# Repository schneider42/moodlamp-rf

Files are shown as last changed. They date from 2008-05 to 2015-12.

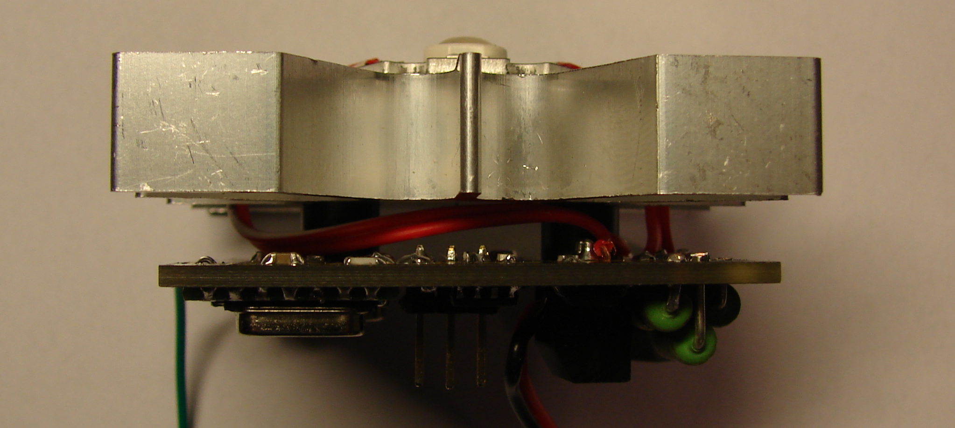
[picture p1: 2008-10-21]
media/side.jpeg

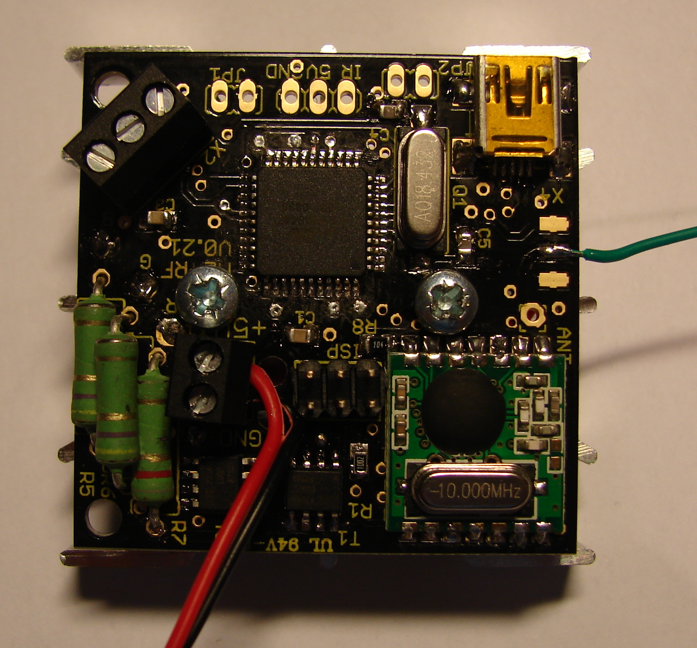
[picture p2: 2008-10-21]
media/bot.jpeg

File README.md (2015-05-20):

# moodlamp
The moodlamp allows to change color in RGB colorspace.

Some art has been done with the help of moodlamps:
- ACAB (AllColourAreBeautiful) https://wiki.muc.ccc.de/acab:start
- Die Drei C https://wiki.muc.ccc.de/diedreic

# r3 version and earlier versions
Earlier versions are developed with ATmega324P, ATmega644P, ... For RS485 usage, change the MCU section in the file ubloader/Makefile.

# r4 version (2th quarter 2015)
Latest r4 version is designed with ATmega324A. If you get a warning from avrdude "device signature [..] expected signature [..] or use -F to override this check", put the following lines in your avrdude.conf:
```diff
 #------------------------------------------------------------
+# ATmega324A
+#------------------------------------------------------------
+
+# similar to ATmega324P
+
+part parent "m324p"
+    id               = "m324a";
+    desc             = "ATmega324A";
+    signature        = 0x1e 0x95 0x15;
+
+    ocdrev           = 3;
+  ;
+
+#------------------------------------------------------------
 # ATmega324PA
 #------------------------------------------------------------
```
For RS485 usage, also double check the MCU part in the file ubloader/Makefile.

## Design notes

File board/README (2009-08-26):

                          Moodlamp-rf pcb readme

This directory contains all files needed to build a moodlamp-rf board. Please use eagle in version 5 to view ml-rf.sch and ml-rf.brd

If you don't have eagle installed you can view the board using ml-rf-{brd,sch}.{png,pdf}

Please view the schematic to see which parts you have to put on the board. Different options are grouped together.
The file bom-grouped contains the list of parts used to build your moodlamp.

Special Notes:
R23 changed it's name to L1.

Parts not populated or replaced:
Some parts are not populated and some have been replaced by solder bridges:

Parts not populated:                    R13, R14, R15
Parts replaced by a solder bridge:      L1, R10, R11, R12

The 3V regulater is usually not populated. These parts are probably not included in your kit.

Parts not populated: C6, C7, C8, C9, C10, IC3
Solderbridge to short out: SJ1

Please refer to https://wiki.muc.ccc.de/geekend08:moodlamp_howto for more information about building a moodlamp.

For an introduction to SMD soldering visit http://www.spida.net/projects/hardware/smd-soldering/

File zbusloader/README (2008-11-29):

zbusloader v0.01
-------------------

zbusloader is a bootloader application targetted at the Atmel AVR
ATmega8.  In theory it should work for other devices but since
it heavily relies on assembler code, especially regarding the
startup code, this probably requires quite some adjustments.

One of the main design goals is to keep the loader small in flash
memory footprint.  This is I shouldn't ever be more than 512 bytes long.

a) Using zbusloader

   * make sure you've got gcc-avr and avr-libc installed

   * edit pinconfig.h to fit your needs

   * Type `make' to compile the whole thing.

   * If everything goes well, type `make load' to flash the
     bootloader code to your device.  Maybe you need to modify the
     command, i.e. the Makefile.

   * In order to adjust the fuse bits of your microcontroller you
     might want to use `make fuse'.

   In order to flash data, use the zbusloader application from below
   contrib.  Use it something like 

   	     contrib/zbusloader -H 192.168.23.244 -f myfile.bin

   where -H specifies the IP address of your (bridging) ethersex.
   Don't forget to enable `zbus_raw' on it.

b) Hacking zbusloader (and what hacks I used already)

   Just a few notes to get you started in zbusloader hacking:

   * zbusloader does NOT rely on avr-libc's standard startup code,
     mainly for size reasons.  This is

      * you must NOT activate any other interrupts, since there is no
        intact interrupt vector table

      * don't just `sei' if you want to, this reenables the overflow
        interrupt of timer 1, see below.

      * my startup code does NOT initialize .bss and .data, this is
        your global variables will not have the values you expect.

   * TIMER 1 OVF interrupt abuse:
     The current bootloader timeout implementation works like this:

      * We initialize the 16-bit timer in such a way that it overflows
        after about 2 seconds.  From the interrupt vector we launch
        the application

      * If we receive a valid bootloading packet we simply disable all
        interrupts, therefore the automatic activation of the
        application.

If it doesn't work, you might want to write an e-mail to
<stesie@brokenpipe.de> or <stettberger@dokucode.de>

Have fun!
  stesie && stettberger

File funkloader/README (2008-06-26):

funkloader v0.01
-------------------

funkloader is a bootloader application targetted at the Atmel AVR
ATmega8.  In theory it should work for other devices but since
it heavily relies on assembler code, especially regarding the
startup code, this probably requires quite some adjustments.

One of the main design goals is to keep the loader small in flash
memory footprint.  This is I shouldn't ever be more than 512 bytes long.

a) Using funkloader

   * make sure you've got gcc-avr and avr-libc installed

   * edit pinconfig.h to fit your needs

   * Type `make' to compile the whole thing.

   * If everything goes well, type `make load' to flash the
     bootloader code to your device.  Maybe you need to modify the
     command, i.e. the Makefile.

   * In order to adjust the fuse bits of your microcontroller you
     might want to use `make fuse'.

   In order to flash data, use the funkloader application from below
   contrib.  Use it something like 

   	     contrib/funkloader -H 192.168.23.244 -f myfile.bin

   where -H specifies the IP address of your (bridging) ethersex.
   Don't forget to enable `rfm12_raw' on it.

b) Hacking funkloader (and what hacks I used already)

   Just a few notes to get you started in funkloader hacking:

   * funkloader does NOT rely on avr-libc's standard startup code,
     mainly for size reasons.  This is

      * you must NOT activate any other interrupts, since there is no
        intact interrupt vector table

      * don't just `sei' if you want to, this reenables the overflow
        interrupt of timer 1, see below.

      * my startup code does NOT initialize .bss and .data, this is
        your global variables will not have the values you expect.

   * TIMER 1 OVF interrupt abuse:
     The current bootloader timeout implementation works like this:

      * We initialize the 16-bit timer in such a way that it overflows
        after about 2 seconds.  From the interrupt vector we launch
        the application

      * If we receive a valid bootloading packet we simply disable all
        interrupts, therefore the automatic activation of the
        application.

If it doesn't work, you might want to write an e-mail to
<stesie@brokenpipe.de>

Have fun!
  stesie

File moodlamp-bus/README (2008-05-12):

----moodlamp-ng---

This is a modified fnordlicht firmware by Tobias Schneider
(schneider@blinkenlichts.net).

It adds a more useful RC5 interface to control the lamp via
an infrared remote control.

Most of the added code goes to the static scripts and the rc5 handler.
The main loop contains a new state machine which controls the global
behavior of the lamp.

A list of features:
    -Dimming the lamp.
    -Powering down the lamp and resuming at the same state.
    -Storing default values in the internal eeprom, which are used at start up.
    -Selection of the running script.
    -Pausing the running script.
    -Adjusting the speed of the script running.
    -A sleep timer which dims the lamp over a period of time to zero brightness.
    -The RGB value can be directly modified by the remote.
     If this is used while the lamp is paused, any color can be selected.

Changes in the source:
    -The original RC5 decoder is replaced by Peter Dannegers code.
    -The speed adjustment is more thoroughly implemented.
    -The PWM values are scaled by a dimming value.
    -The RC5 commands are handled in a new module(rc5_handler.c)
    -The standard avr-lib makefile is used.
    -The pin for the RC5 receiver changed. This is due to the chosen layout.
     With the new RC5 lib this can be changed to any pin.

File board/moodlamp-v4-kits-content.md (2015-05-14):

```
Part                                Type        Value           Marking
IC1                                 MCU         ATMEGA324A-20AU ATMEGA324A AU
IC2                                 RS485 TRX   MAX487          MAX487
IC4                                 Regulator   LM2596DSADJG    2596-ADJ
T1, T2                              Transistor  IRF7103         F7103

C1, C2, C3, C7, C11, C12, C13, C14  Capacitor   100 nF          neutral marking on tape, 10 devices
C4, C5                              Capacitor   22 pF           red marking on tape, 2 devices
C6                                  Capacitor   6.8 nF          neutral marking on tape, 1 device
C8                                  Capacitor   10 uF           "Big Capacitor"
C9                                  Capacitor   220 uF/50 V     220 HFK
C10                                 Capacitor   470 uF/25 V     470 EFK

R1,R3                               Resistor    10 KOhm         1002, black marking on tape
R2                                  Resistor    150 kOhm        1503, blue marking on tape, 1 device
R4                                  Resistor    1 kOhm          1001, yellow marking on tape, 1 device
R5, R6                              Resistor    4.7 Ohm         Yellow-Purple-Gold-Gold
R7                                  Resistor    8.2 Ohm         Purple-Red-Gold-Gold
R9                                  Resistor    3.09 kOhm       purple marking on tape, 1 device

L1                                  Inductor    68 uH           "Big Inductor"
L2, L3                              Ferrite     120 Ohm         neutral marking on tape, 2 devices, small

D1                                  Diode       MBRS240         SK24
Q1                                  Crystal     18.432 MHz      18.432

DC                                  Connector   -               "Big Connector"
XIN, XOUT                           Connector   Modular 8       "Big Connectors"
ISP                                 Connector   3x2 Header      3x2 Header
JP1                                 Connector   1x2 Header      1x2 Header

LED1                                LED         RGB             "Big LED"
Jumper                              Jumper      Jumper          Black Jumper
```

See also https://wiki.muc.ccc.de/_media/moodlamp-r4-round-passives.jpg

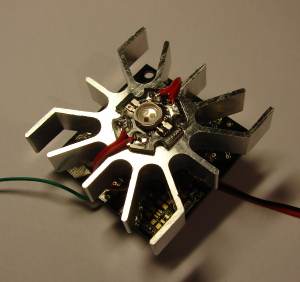
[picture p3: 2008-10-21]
media/ml-scale.jpeg

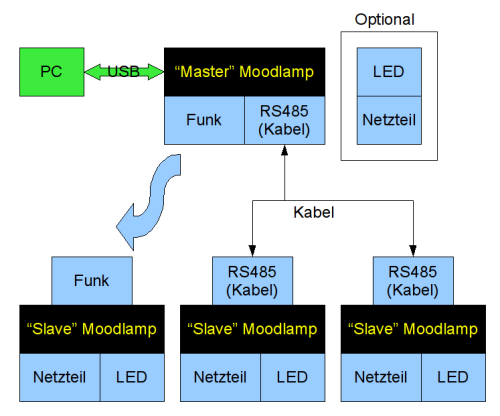
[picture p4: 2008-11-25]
media/schema2.png

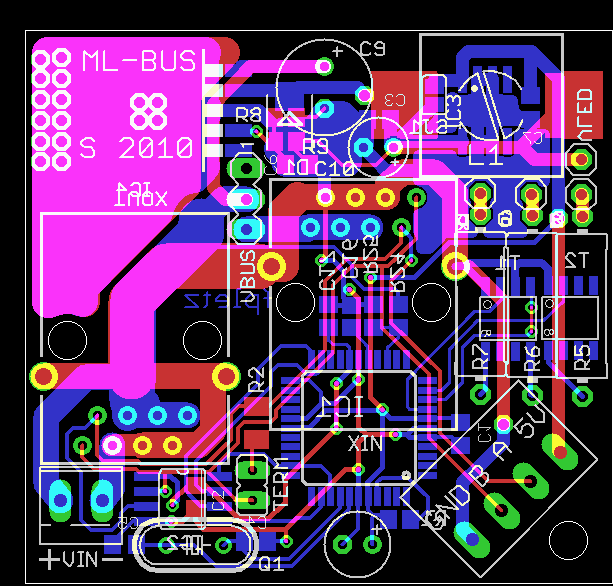
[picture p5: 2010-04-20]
board/buslamp-brd.png

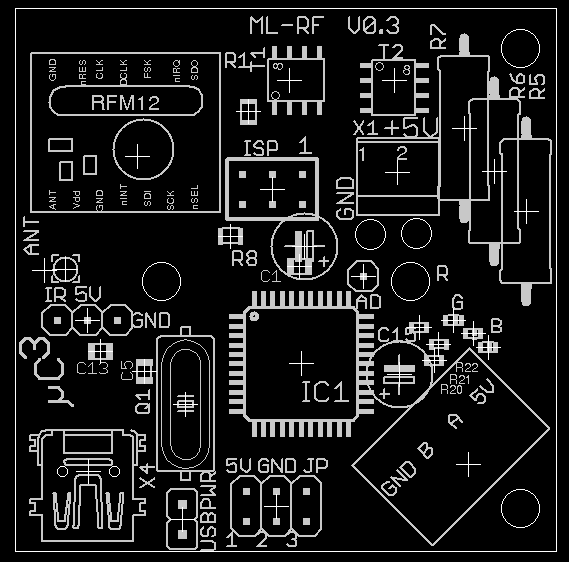
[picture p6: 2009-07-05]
board/top.png

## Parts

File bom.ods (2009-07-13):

Part | Qty.
ATMega644P | 1 | 5,20 € | 5,20 € | ca.
PCB | 1 | 3,00 € | 3,00 €
18,432 MHz SMD | 1 | 0,25 € | 0,25 € |  |  | Bus: | 19,22 €
AKL 059-2 | 1 | 0,15 € | 0,15 €
IRF7103 | 2 | 0,26 € | 0,52 €
100k | 5 | 0,01 € | 0,05 €
10k | 2 | 0,01 € | 0,02 €
100nF | 4 | 0,02 € | 0,08 €
22pF | 2 | 0,02 € | 0,04 €
DC | 1 | 0,15 € | 0,15 €
 |  |  |  | 9,46 €
RFM12 | 1 | 4,50 € | 4,50 €
 |  |  |  | 4,50 €
MAX487 CSA | 1 | 1,82 € | 1,82 €
AKL 166-4 | 1 | 0,84 € | 0,84 €
 |  |  |  | 2,66 €
FT232R | 1 | 3,19 € | 3,19 €
MINI-USB B SMD | 1 | 0,42 € | 0,42 €
100nF | 3 | 0,02 € | 0,06 €
 |  |  |  | 3,67 €
DX RGB | 1 | 6,00 € | 6,00 €
Heatsink | 1 | 1,10 € | 1,10 €
 |  |  |  | 7,10 €
Power Supply | 1 | 3,89 € | 3,89 €
DC | 1 | 0,15 € | 0,15 €
 |  |  |  | 4,04 €
Remote | 1 | 4,00 € | 4,00 €
Tsop 1736 | 1 | 1,10 € | 1,10 €
 |  |  |  | 5,10 € | ohne lampe: | 36,53 €
Ikea Lamp | 1 | 9,00 € | 9,00 €
 |  |  |  | 9,00 € | preis nach wiki: | 43
 |  |  | Full: | 45,53 €
 |  |  | Old: | 34,70 €

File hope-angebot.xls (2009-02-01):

Hope Microelectronics Co., Ltd.
Address: 4/F, Block B3, East Industrial Area, Huaqiaocheng,Shenzhen, Guangdong, China 518052
Tel: 86-755-82973805 ext:826 Fax: 86-755-82973550
Email: euro@hoperf.com Web: http://www.hoperf.com
Quotation Sheet
To: | Chaos Computer Club Muenchen
From: | Hope Microelectronic Co.,Ltd
Date: | 12/09/2008 |  |  |  | Sales: | Mr.Mark Yao
Payment Term : | T/T in advance |  |  |  | Leadtime:
Price validity : | 30/12/2008 |  |  |  | Package :
Currency : | USD |  |  |  | Price Term: | Ex-works
Item No. | Description | Qty's
 |  | <500pcs | <1k pcs | 10K
RFM12-D | Transceiver;DIP package | 3.1 | 3 | 2.05
RFM12-S1 | Transceiver;SMD package | 3.1 | 3 | 2
RFM12-S2 | Transceiver;Thin SMD package | 3.4 | 3.3 | 2.3
RFM12B-D | Transceiver;DIP package | 3.1 | 3 | 2.15
RFM12B-S1 | Transceiver;SMD package | 3.1 | 3 | 2.1
RFM12B-S2 | Transceiver;Thin SMD package | 3.4 | 3.3 | 2.4
Demo kit |  | USD 40/pcs
Notes: | The price doesn't include any tax.

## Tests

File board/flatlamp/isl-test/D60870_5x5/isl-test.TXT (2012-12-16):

%
M48
M72
T01C0.0118
T02C0.0400
%
T01
X4273Y1439
X5179Y2502
X6675Y966
X7226Y3210
X7935Y3328
X5572Y5257
X5376Y5454
X5572Y5651
X5179Y5651
X4982Y5454
X5179Y5257
X4785Y5257
X4785Y5651
X4431Y6006
X4785Y6360
X4431Y6439
X5691Y6360
X1872Y6281
T02
X3769Y9155
X4769Y9155
X5769Y9155
X6769Y9155
X7769Y9155
X9982Y8163
X9982Y7163
X9982Y6163
X9982Y5163
X9982Y4163
M30

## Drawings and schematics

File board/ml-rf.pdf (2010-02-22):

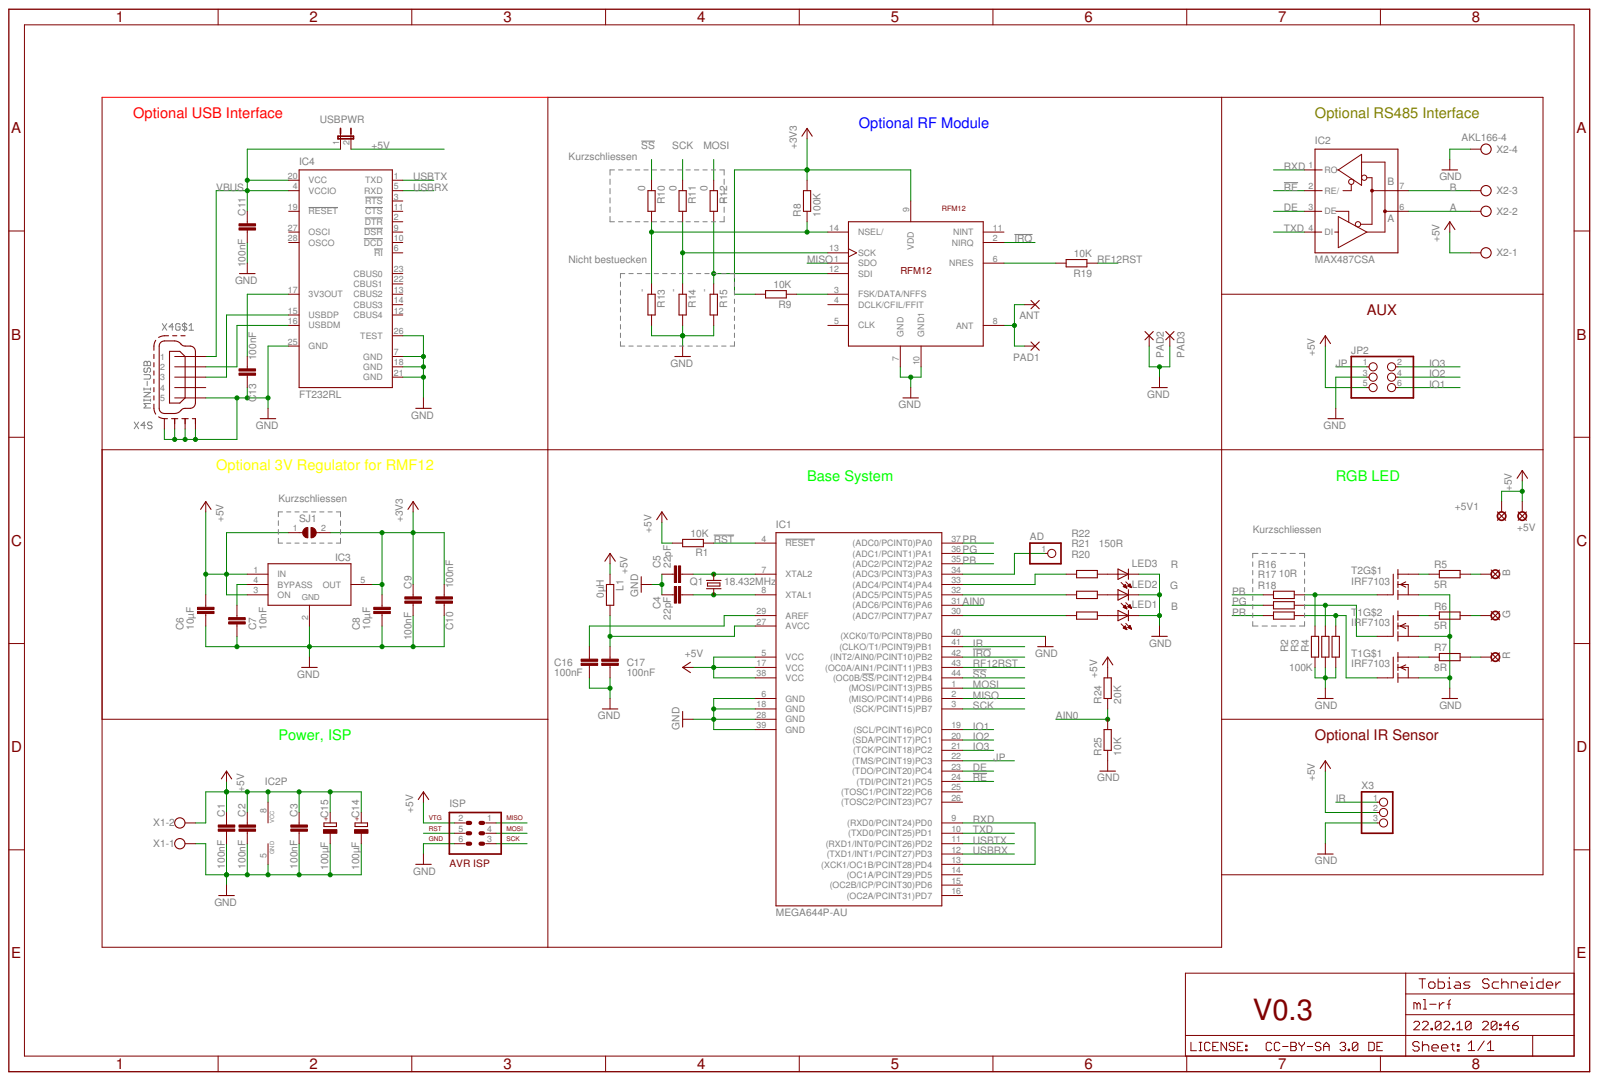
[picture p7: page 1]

Optional RF Module Optional USB Interface | Optional RS485 Interface IC2 AKL166-4

MISO

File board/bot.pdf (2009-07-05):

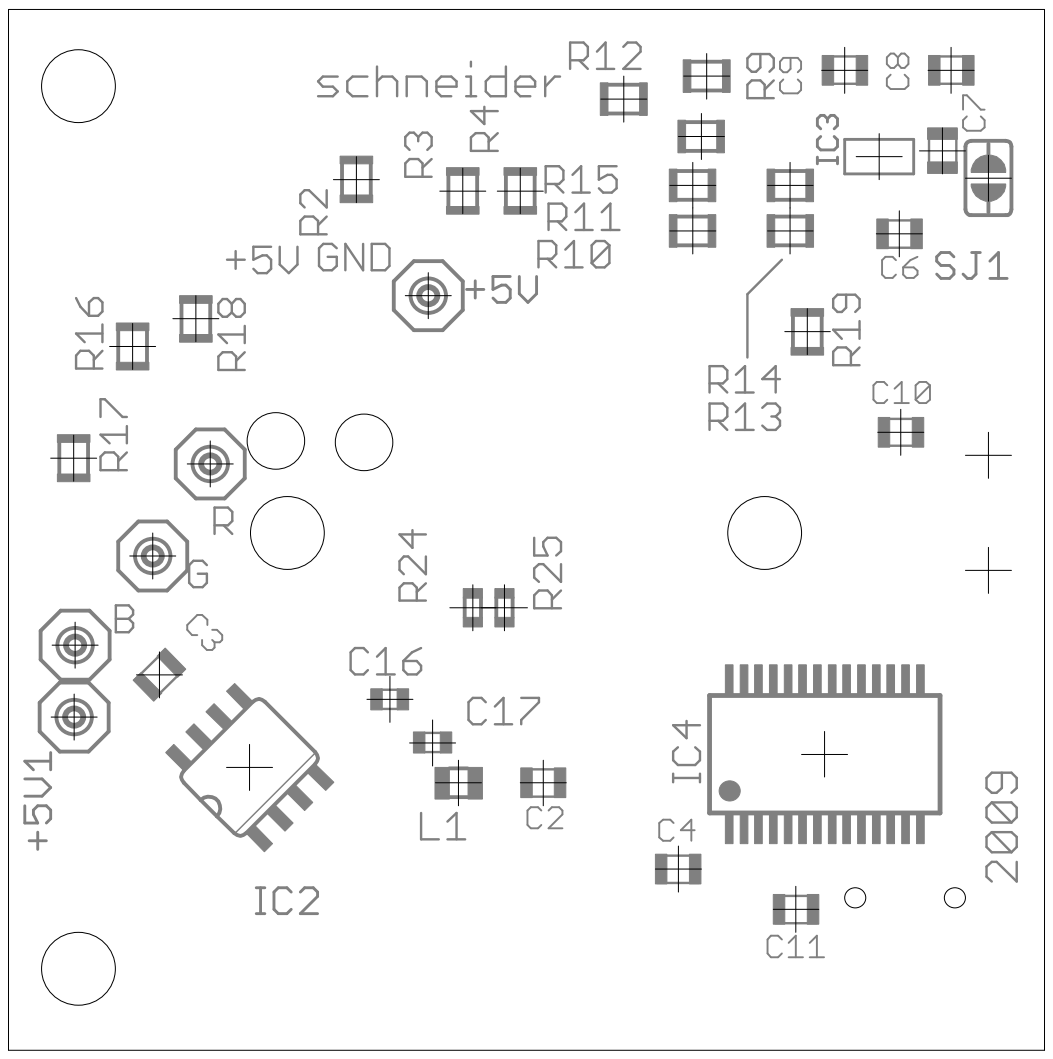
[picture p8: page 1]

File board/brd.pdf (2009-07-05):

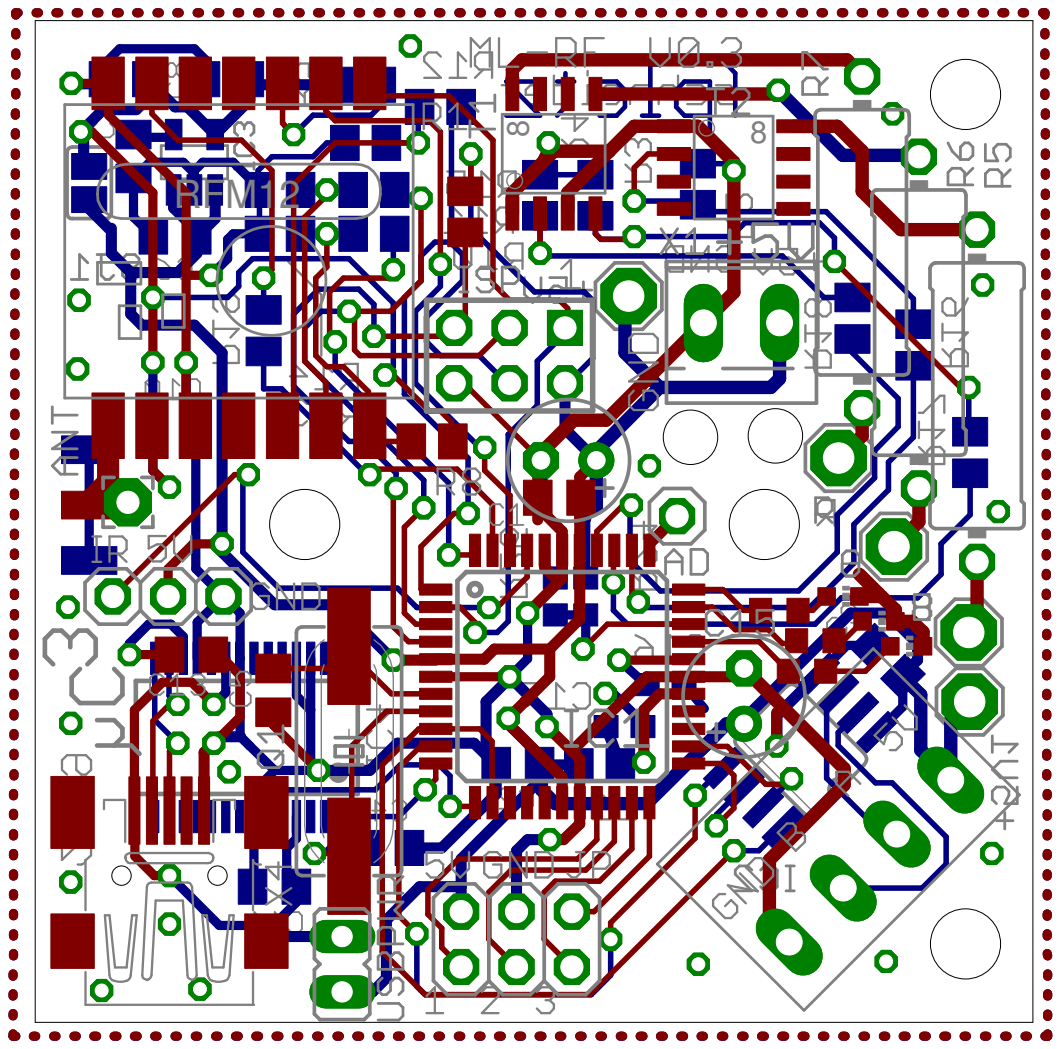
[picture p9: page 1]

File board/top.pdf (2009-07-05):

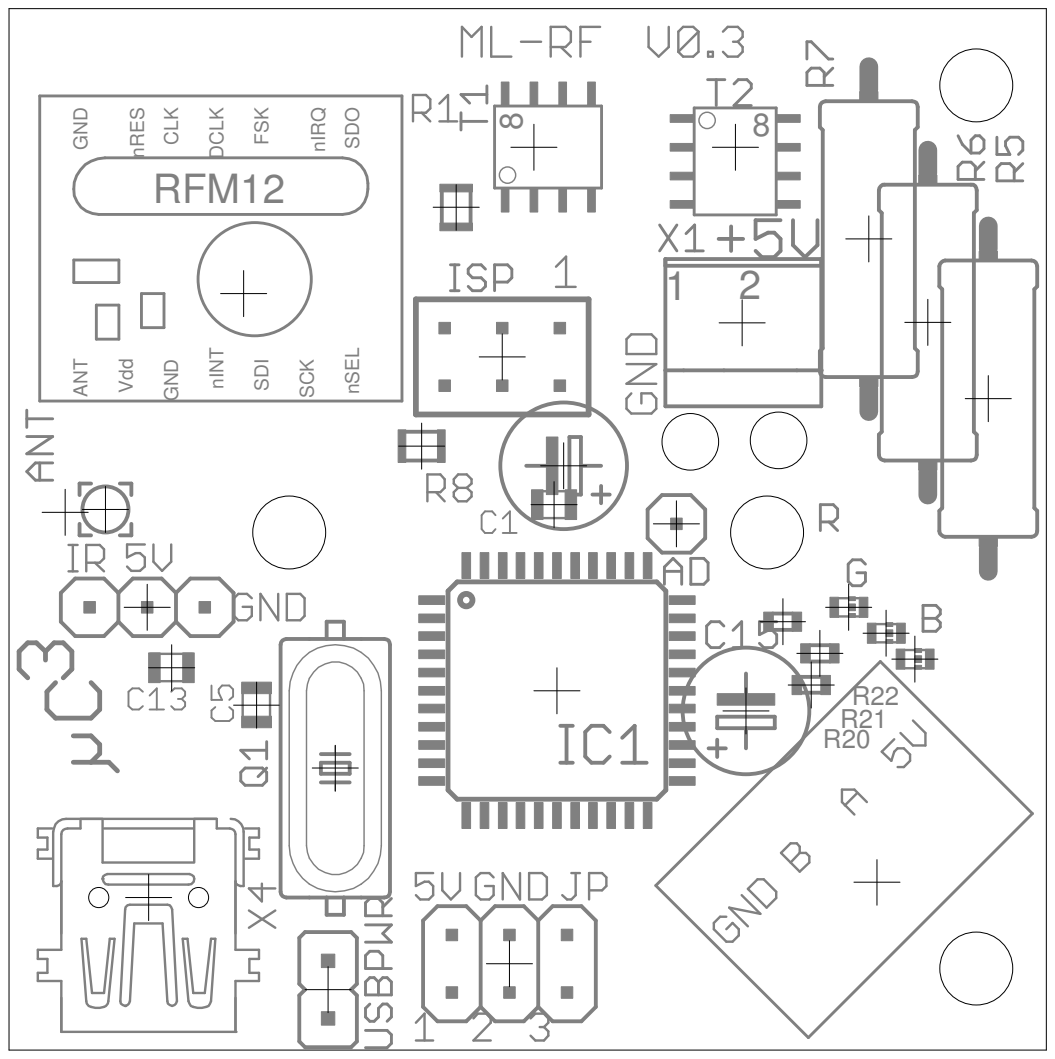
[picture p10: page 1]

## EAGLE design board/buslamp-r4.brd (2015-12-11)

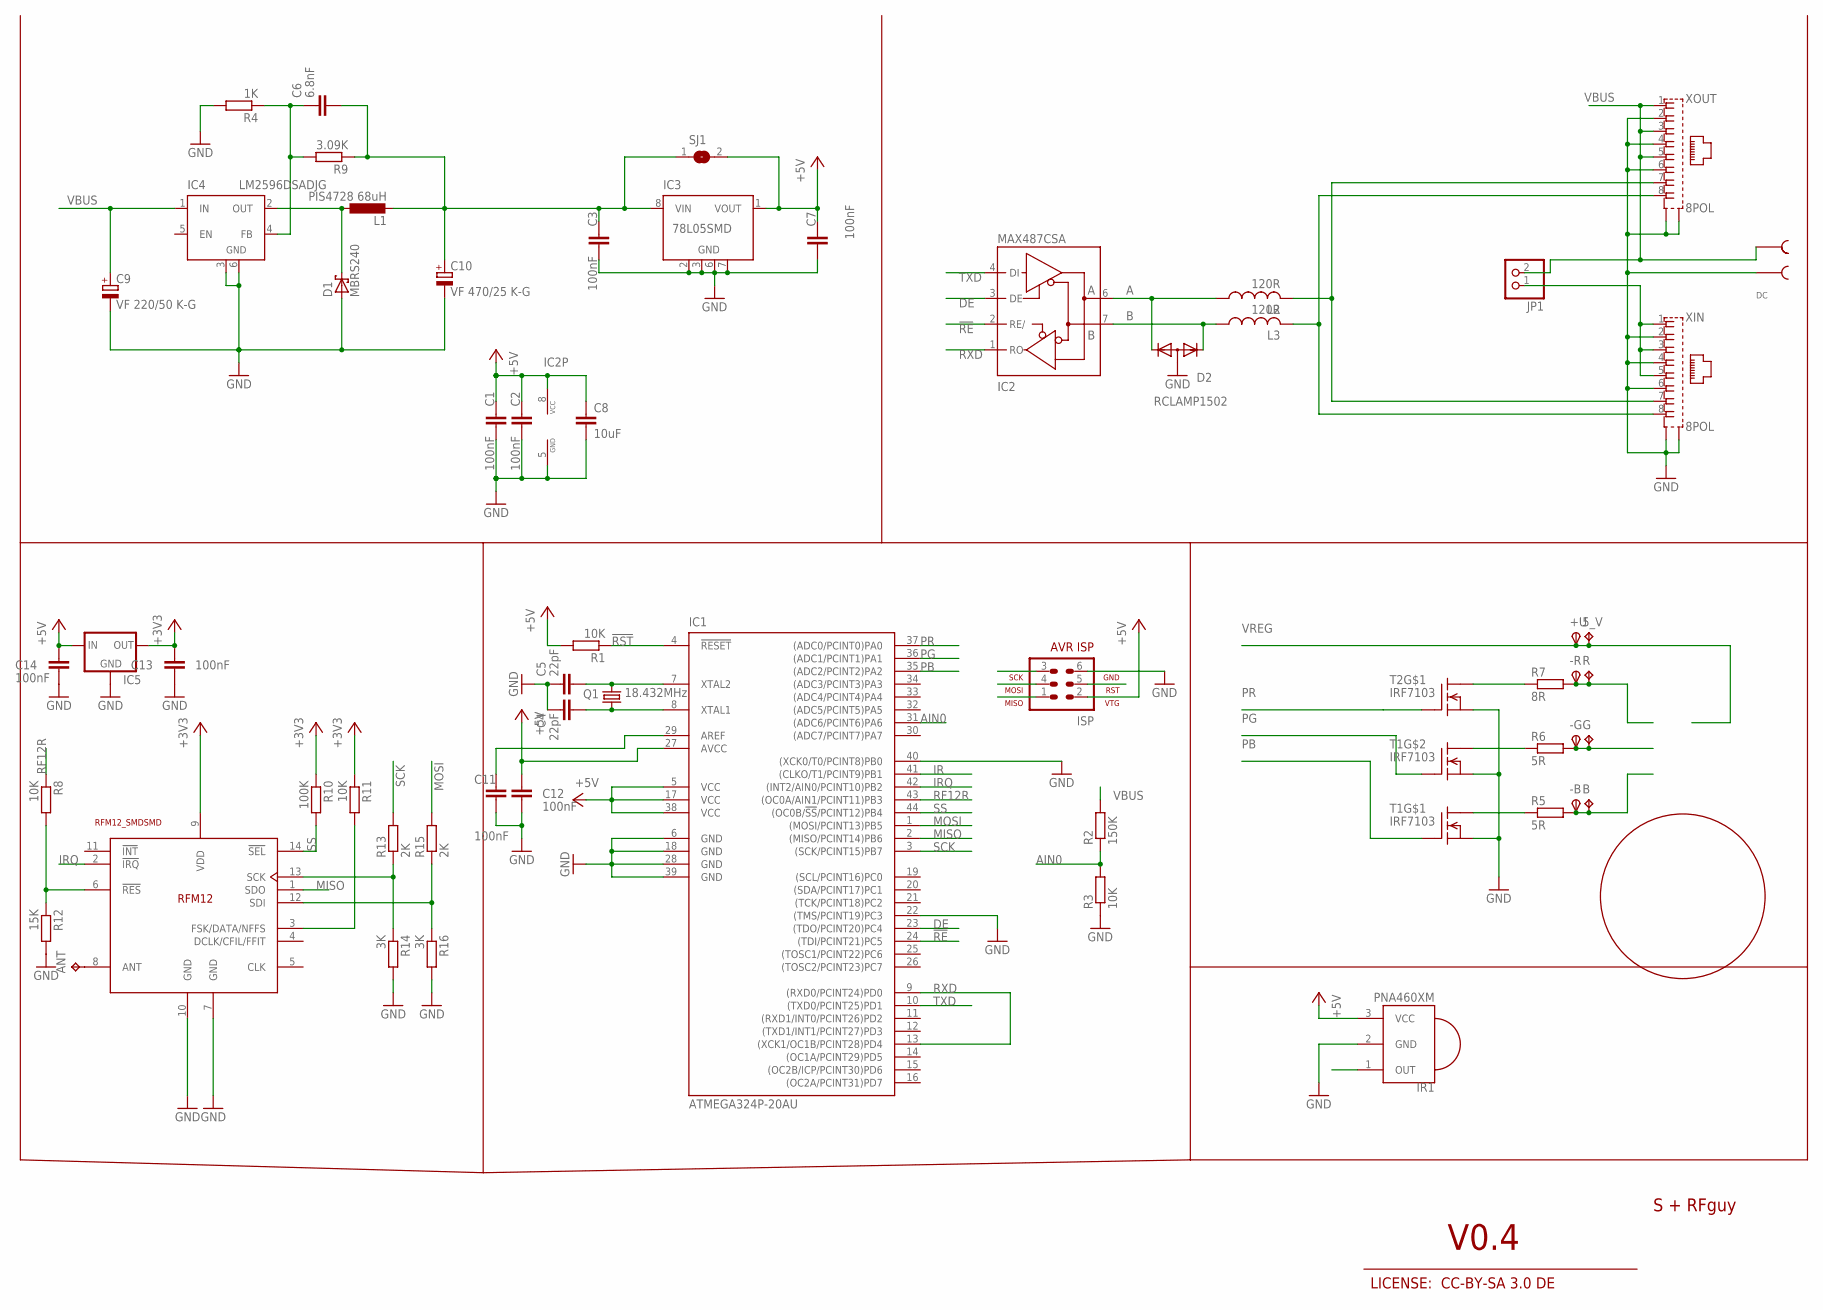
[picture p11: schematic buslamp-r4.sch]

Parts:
5_V: TPPAD1-13; P1-13
+U: TPSTP212R; TP212R
-B: TPSTP212R; TP212R
-G: TPSTP212R; TP212R
-R: TPSTP212R; TP212R
ANT: TPPAD1-13; P1-13
B: TPPAD1-13; P1-13
C1, C2, C3, C7: 100nF; C0805K
C4, C5: 22pF; C0805K
C6: 6.8nF; C0805K
C8: 10uF; C1210
C9: VF 220/50 K-G; UD-10X10_NICHICON
C10: VF 470/25 K-G; UD-10X10_NICHICON
C11, C12, C13, C14: 100nF; C0805
D1: MBRS240; SMB
D2: RCLAMP1502; SOT23
DC: STL-266-2
G: TPPAD1-13; P1-13
IC1: ATMEGA324P-20AU; TQFP44
IC2: MAX487CSA; SO08
IC3: 78L05SMD; SO08
IC4: LM2596DSADJG; TO263-5
IC5: MCP1700SOT23; SOT23
IR1: PNA460XM
ISP: AVR-ISP-6
JP1: PINHD-1X2; 1X02
L1: PIS4728 68uH; PIS4728
L2, L3: 120R; L0603
Q1: 18.432MHz; HC49/S
R: TPPAD1-13; P1-13
R1, R8, R11: 10K; M0805
R2: 150K; R0805
R3: 10K; R0805
R4: 1K; M0805
R5, R6: 5R; 0617/17
R7: 8R; 0617/17
R9: 3.09K; M0805
R10: 100K; M0805
R12: 15K; M0805
R13, R15: 2K; M0805
R14, R16: 3K; M0805
RF1: RFM12_SMDSMD; RFM12
SJ1: SJ
T1, T2: IRF7103; SO-8
U$2: KK-STERN; STERN
XIN: 8POL
XOUT: 8POL

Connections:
!RE: IC1.24 ((TDI/PCINT21)PC5), IC2.2 (RE/)
!RST: IC1.4 (!RESET), ISP.5, R1.1
+3V3: C13.2, IC5.2 (OUT), R10.1, R11.1, RF1.9 (VDD)
+5V: C1.1, C2.1, C7.1, C8.1, C12.2, C14.2, IC1.5 (VCC), IC1.17 (VCC), IC1.27 (AVCC), IC1.38 (VCC), IC2.8 (VCC), IC3.1 (VOUT), IC5.3 (IN), IR1.3 (VCC), ISP.2, R1.2, SJ1.2
A: L2.2, XIN.7, XOUT.7
AIN0: IC1.31 ((ADC6/PCINT6)PA6), R2.1, R3.2
B: L3.2, XIN.8, XOUT.8
DE: IC1.23 ((TDO/PCINT20)PC4), IC2.3 (DE)
G: -G.TP, G.TP, R6.2
GND: C1.2, C2.2, C3.2, C4.1, C5.1, C7.2, C8.2, C9.-, C10.-, C11.1, C12.1, C13.1, C14.1, D1.A, D2.3 (A), DC.P$3, IC1.6 (GND), IC1.18 (GND), IC1.22 ((TMS/PCINT19)PC3), IC1.28 (GND), IC1.39 (GND), IC1.40 ((XCK0/T0/PCINT8)PB0), IC2.5 (GND), IC3.2 (GND), IC3.3 (GND), IC3.6 (GND), IC3.7 (GND), IC4.3 (GND), IC4.6 (GND), IC5.1 (GND), IR1.2 (GND), ISP.6, R3.1, R4.2, R12.2, R14.2, R16.2, RF1.7 (GND), RF1.10 (GND), T1.1 (S), T1.3 (S), T2.1 (S), XIN.2, XIN.4, XIN.6, XIN.S1, XIN.S2, XOUT.2, XOUT.4, XOUT.6, XOUT.S1, XOUT.S2
IR: IC1.41 ((CLKO/T1/PCINT9)PB1), IR1.1 (OUT)
IRQ: IC1.42 ((INT2/AIN0/PCINT10)PB2), RF1.2 (!IRQ)
MISO: IC1.2 ((MISO/PCINT14)PB6), ISP.1, RF1.1 (SDO)
MOSI: IC1.1 ((MOSI/PCINT13)PB5), ISP.4, R15.2
unnamed: R7.1, T2.8 (D1)
unnamed: R8.2, R12.1, RF1.6 (!RES)
unnamed: C6.1, IC4.4 (FB), R4.1, R9.2
unnamed: R6.1, T1.5 (D1)
unnamed: R5.1, T1.8 (D1)
unnamed: -B.TP, B.TP, R5.2
unnamed: R13.1, R14.1, RF1.13 (SCK)
unnamed: R15.1, R16.1, RF1.12 (SDI)
unnamed: ANT.TP, RF1.8 (ANT)
unnamed: D1.C, IC4.2 (OUT), L1.1
unnamed: D2.2 (K2), IC2.6 (A), L2.1
unnamed: D2.1 (K1), IC2.7 (B), L3.1
unnamed: R11.2, RF1.3 (FSK/DATA/NFFS)
unnamed: C11.2, IC1.29 (AREF)
PB: IC1.35 ((ADC2/PCINT2)PA2), T1.2 (G)
PG: IC1.36 ((ADC1/PCINT1)PA1), T1.4 (G)
PR: IC1.37 ((ADC0/PCINT0)PA0), T2.2 (G)
R: -R.TP, R.TP, R7.2
RF12R: IC1.43 ((OC0A/AIN1/PCINT11)PB3), R8.1
RXD: IC1.9 ((RXD0/PCINT24)PD0), IC1.13 ((XCK1/OC1B/PCINT28)PD4), IC2.1 (RO)
SCK: IC1.3 ((SCK/PCINT15)PB7), ISP.3, R13.2
SS: IC1.44 ((OC0B/!SS!/PCINT12)PB4), R10.2, RF1.14 (!SEL)
TXD: IC1.10 ((TXD0/PCINT25)PD1), IC2.4 (DI)
VBUS: C9.+, DC.P$4, IC4.1 (IN), JP1.2, R2.2, XOUT.1, XOUT.3, XOUT.5
VBUSOUT: JP1.1, XIN.1, XIN.3, XIN.5
VREG: 5_V.TP, +U.TP, C3.1, C6.2, C10.+, IC3.8 (VIN), L1.2, R9.1, SJ1.1
XTAL1: C5.2, IC1.7 (XTAL2), Q1.2
XTAL2: C4.2, IC1.8 (XTAL1), Q1.1

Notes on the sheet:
S + RFguy
V0.4
LICENSE: CC-BY-SA 3.0 DE
RF12R
IRQ
MOSI
MISO
SCK

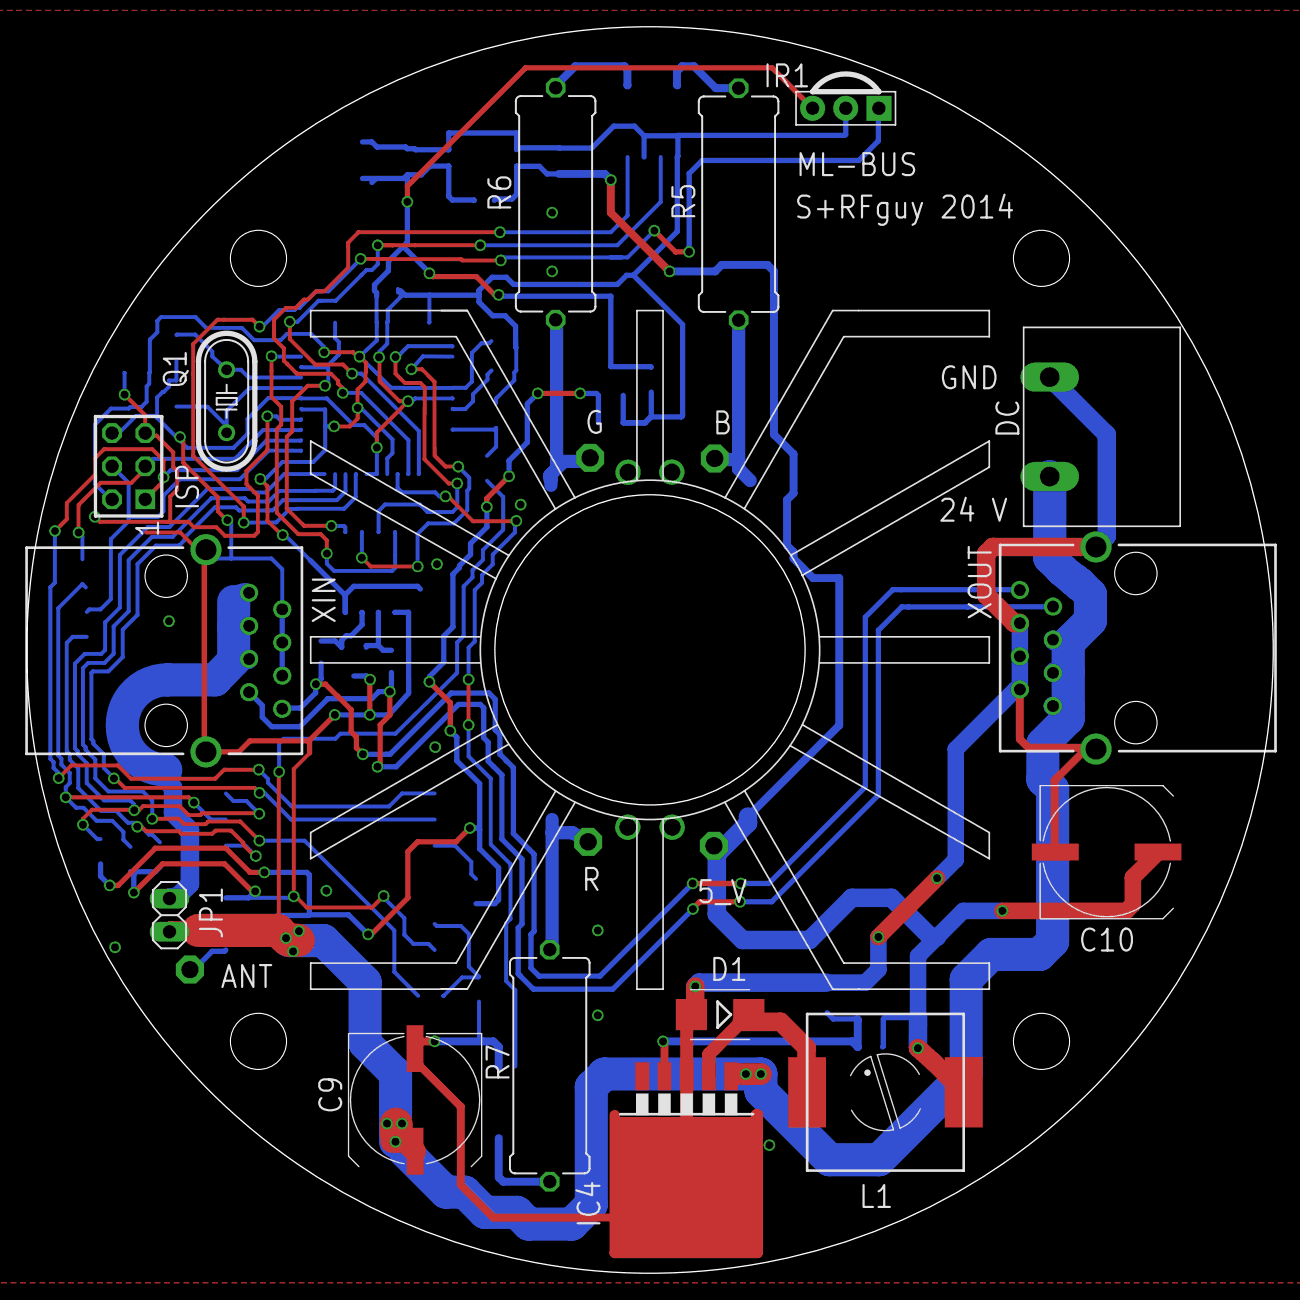
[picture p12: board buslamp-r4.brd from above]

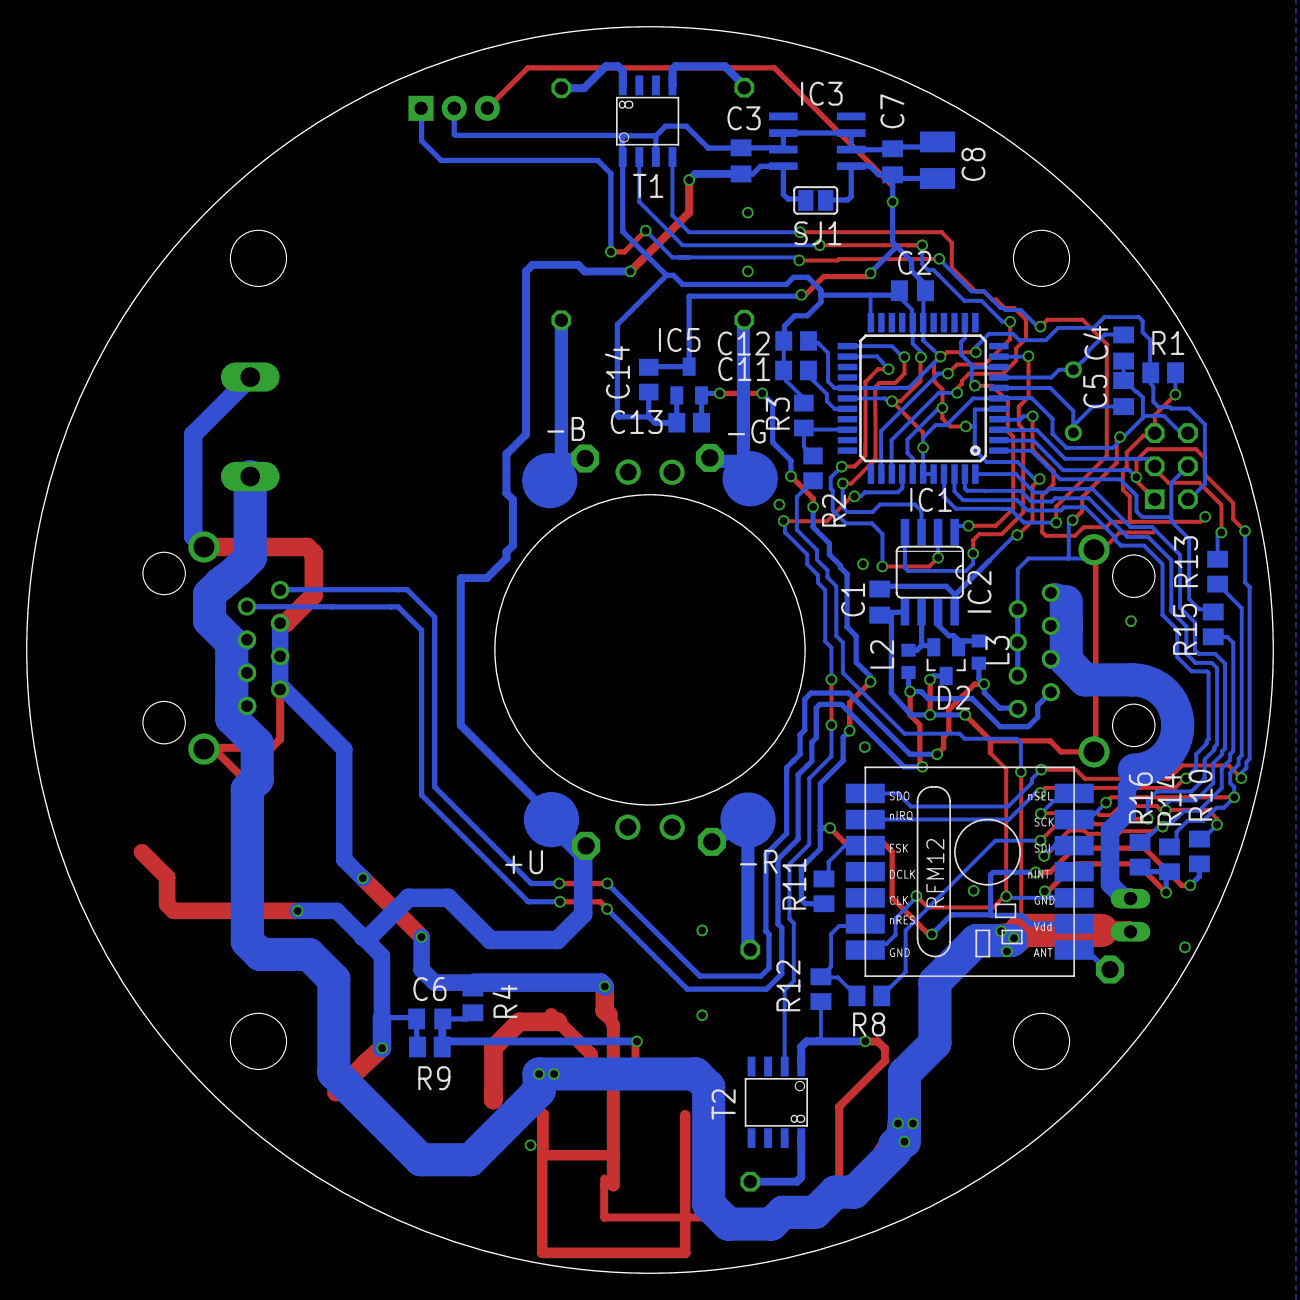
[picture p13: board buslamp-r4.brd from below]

Board: 2 copper layers, 95.5 x 95.5 mm, 61 parts (40 on the bottom side), 42 nets.

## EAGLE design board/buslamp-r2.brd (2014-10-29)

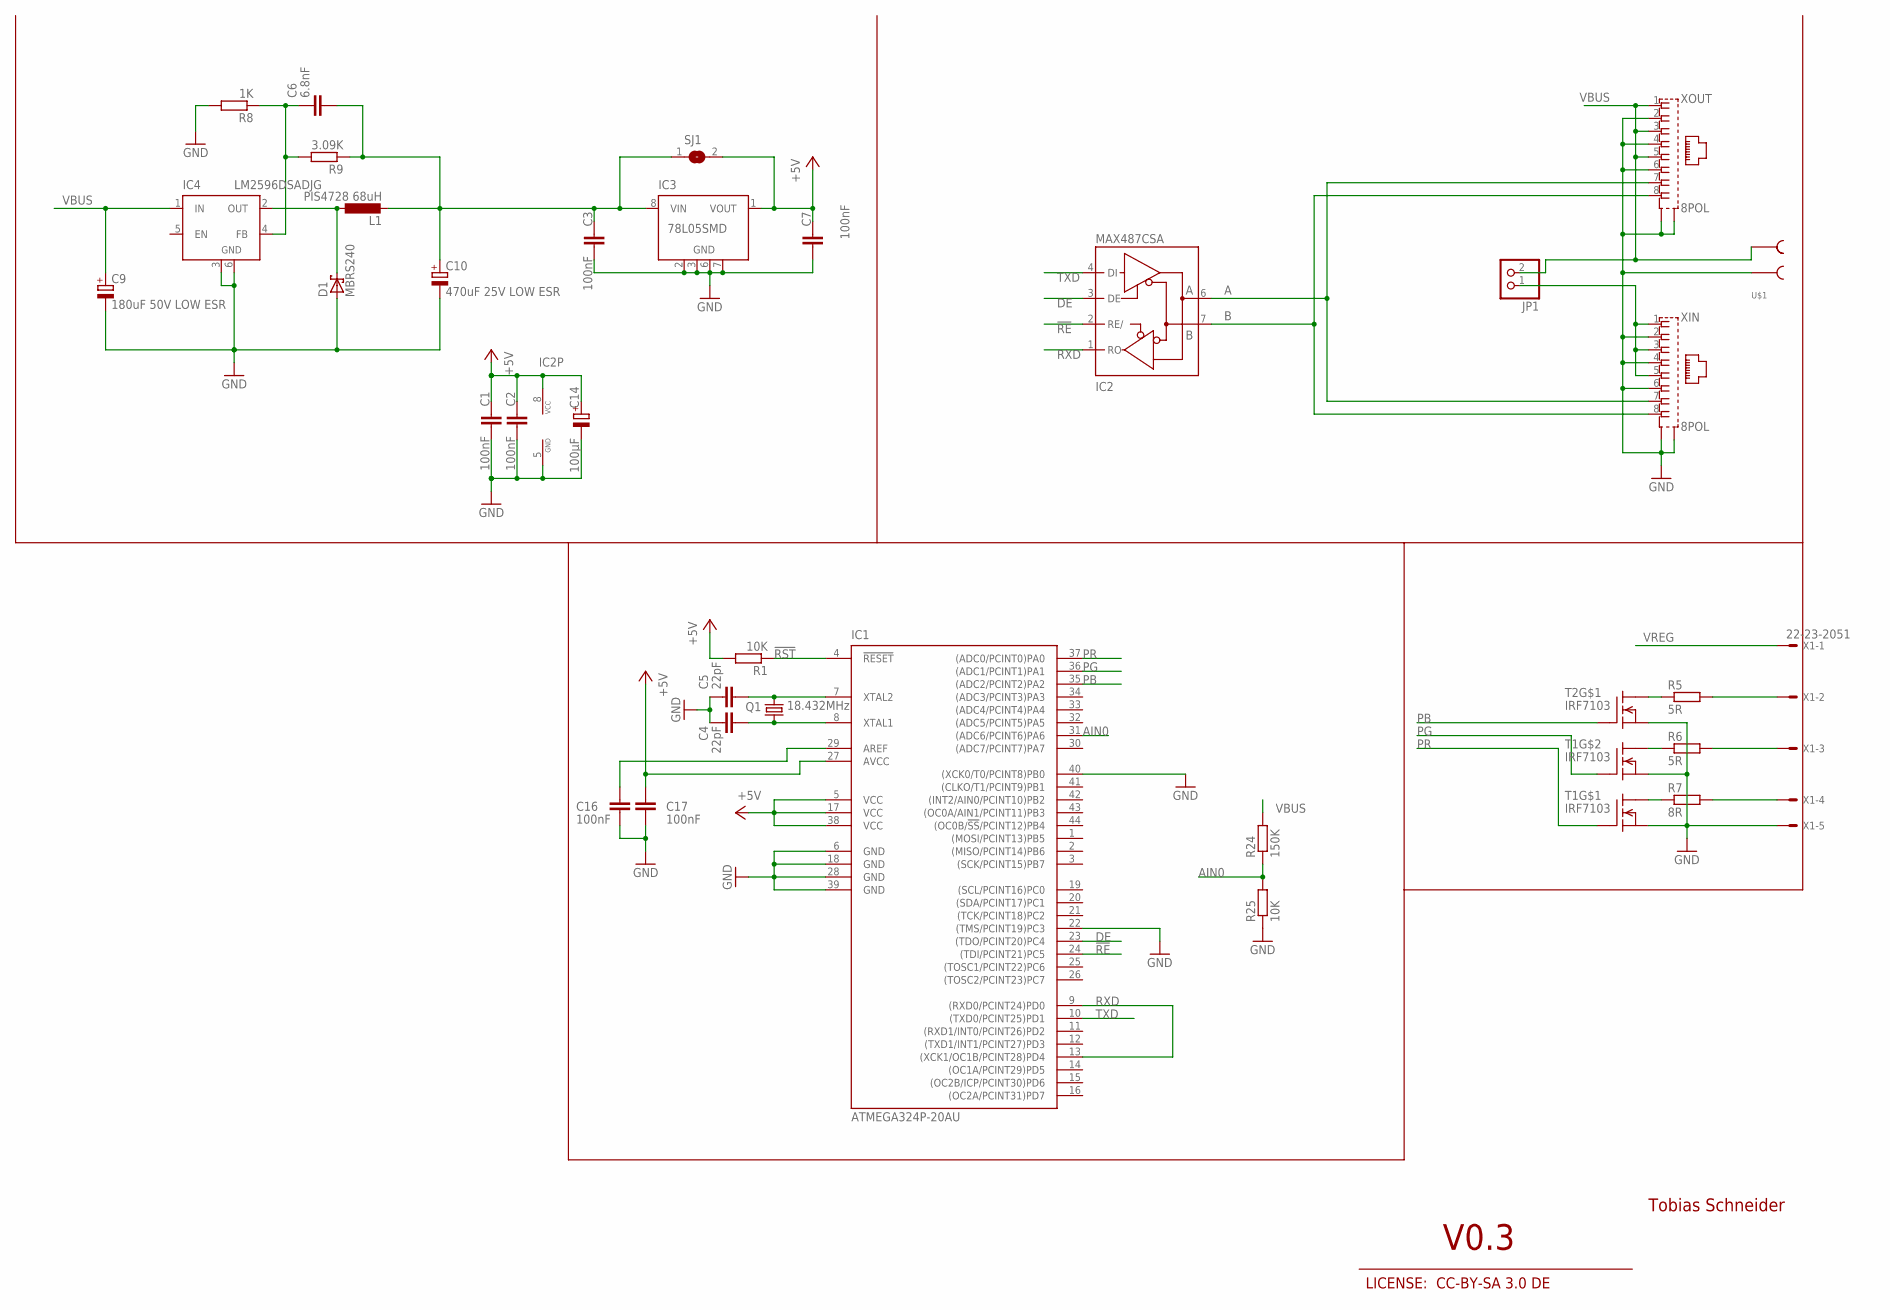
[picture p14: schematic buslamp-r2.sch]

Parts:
C1, C2, C3, C7: 100nF; C0805K
C4, C5: 22pF; C0805K
C6: 6.8nF; C0805K
C9: 180uF 50V LOW ESR; E3,5-8
C10: 470uF 25V LOW ESR; E2,5-7
C14: 100µF; E2,5-6
C16, C17: 100nF; C0805
D1: MBRS240; SMB
IC1: ATMEGA324P-20AU; TQFP44
IC2: MAX487CSA; SO08
IC3: 78L05SMD; SO08
IC4: LM2596DSADJG; TO263-5
JP1: PINHD-1X2; 1X02
L1: PIS4728 68uH; PIS4728
Q1: 18.432MHz; HC49/S
R1: 10K; M0805
R5, R6: 5R; 0617/17
R7: 8R; 0617/17
R8: 1K; M0805
R9: 3.09K; M0805
R24: 150K; R0805
R25: 10K; R0805
SJ1: SJ
T1, T2: IRF7103; SO-8
U$1: STL-266-2
X1: 22-23-2051
XIN: 8POL
XOUT: 8POL

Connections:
!RE: IC1.24 ((TDI/PCINT21)PC5), IC2.2 (RE/)
!RST: IC1.4 (!RESET), R1.1
+5V: C1.1, C2.1, C7.1, C14.+, C17.2, IC1.5 (VCC), IC1.17 (VCC), IC1.27 (AVCC), IC1.38 (VCC), IC2.8 (VCC), IC3.1 (VOUT), R1.2, SJ1.2
A: IC2.6 (A), XIN.7, XOUT.7
AIN0: IC1.31 ((ADC6/PCINT6)PA6), R24.1, R25.2
B: IC2.7 (B), XIN.8, XOUT.8
DE: IC1.23 ((TDO/PCINT20)PC4), IC2.3 (DE)
GND: C1.2, C2.2, C3.2, C4.1, C5.1, C7.2, C9.-, C10.-, C14.-, C16.1, C17.1, D1.A, IC1.6 (GND), IC1.18 (GND), IC1.22 ((TMS/PCINT19)PC3), IC1.28 (GND), IC1.39 (GND), IC1.40 ((XCK0/T0/PCINT8)PB0), IC2.5 (GND), IC3.2 (GND), IC3.3 (GND), IC3.6 (GND), IC3.7 (GND), IC4.3 (GND), IC4.6 (GND), R8.2, R25.1, T1.1 (S), T1.3 (S), T2.1 (S), U$1.P$3, X1.5, XIN.2, XIN.4, XIN.6, XIN.S1, XIN.S2, XOUT.2, XOUT.4, XOUT.6, XOUT.S1, XOUT.S2
unnamed: R7.1, T1.8 (D1)
unnamed: C6.1, IC4.4 (FB), R8.1, R9.2
unnamed: R6.1, T1.5 (D1)
unnamed: R5.1, T2.8 (D1)
unnamed: R7.2, X1.4
unnamed: R6.2, X1.3
unnamed: R5.2, X1.2
unnamed: D1.C, IC4.2 (OUT), L1.1
unnamed: C16.2, IC1.29 (AREF)
PB: IC1.35 ((ADC2/PCINT2)PA2), T2.2 (G)
PG: IC1.36 ((ADC1/PCINT1)PA1), T1.4 (G)
PR: IC1.37 ((ADC0/PCINT0)PA0), T1.2 (G)
RXD: IC1.9 ((RXD0/PCINT24)PD0), IC1.13 ((XCK1/OC1B/PCINT28)PD4), IC2.1 (RO)
TXD: IC1.10 ((TXD0/PCINT25)PD1), IC2.4 (DI)
VBUS: C9.+, IC4.1 (IN), JP1.2, R24.2, U$1.P$4, XOUT.1, XOUT.3, XOUT.5
VBUSOUT: JP1.1, XIN.1, XIN.3, XIN.5
VREG: C3.1, C6.2, C10.+, IC3.8 (VIN), L1.2, R9.1, SJ1.1, X1.1
XTAL1: C5.2, IC1.7 (XTAL2), Q1.2
XTAL2: C4.2, IC1.8 (XTAL1), Q1.1

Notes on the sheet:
Tobias Schneider
V0.3
LICENSE: CC-BY-SA 3.0 DE

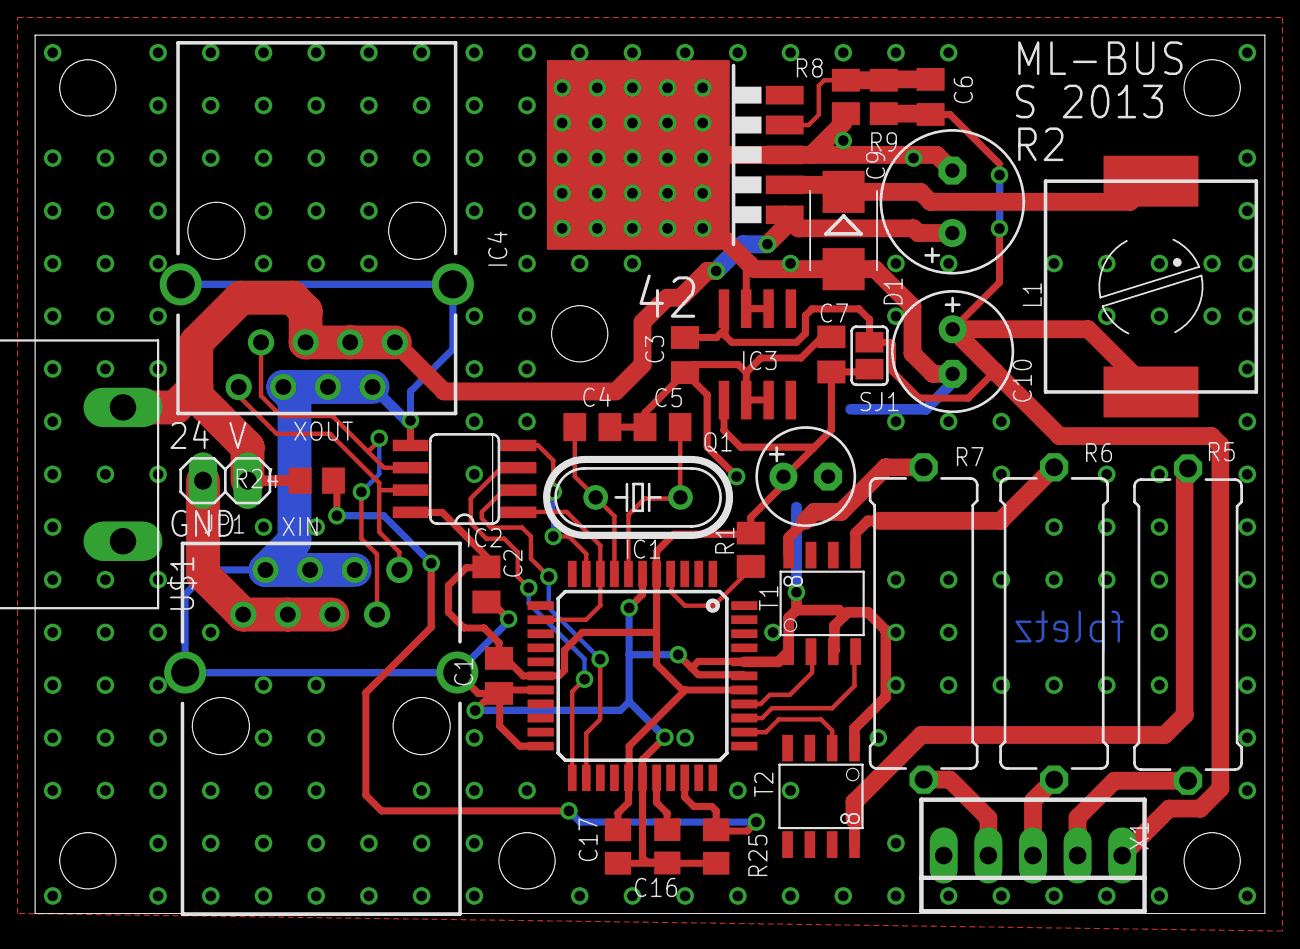
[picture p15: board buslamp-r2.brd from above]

Board: 2 copper layers, 70.0 x 50.0 mm, 35 parts (0 on the bottom side), 27 nets.

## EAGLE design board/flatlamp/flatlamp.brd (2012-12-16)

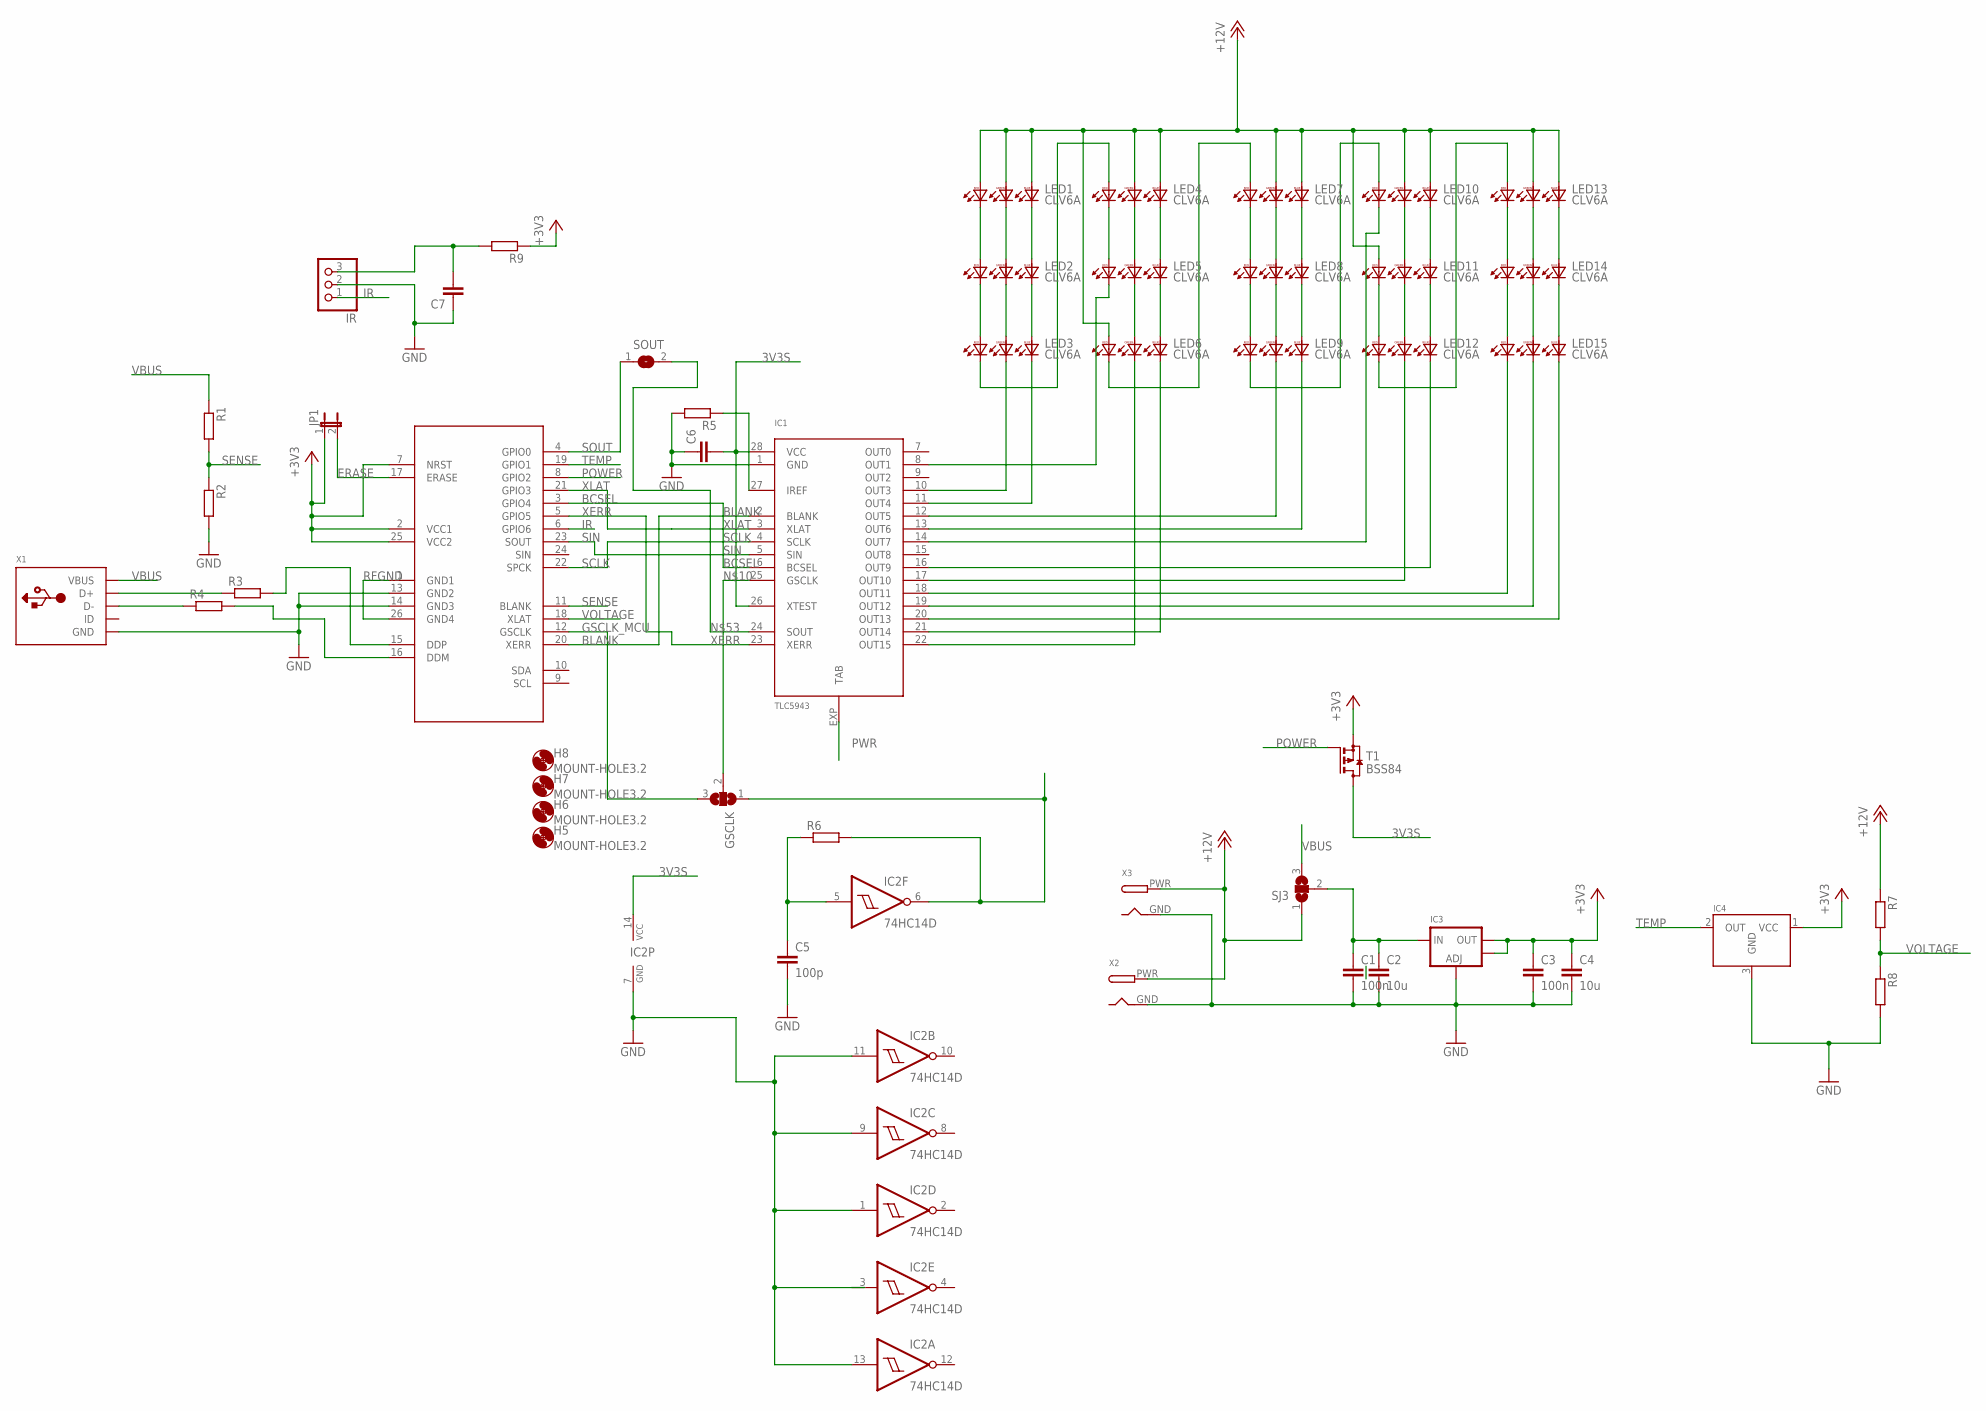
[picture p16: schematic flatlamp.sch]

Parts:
C1, C3: 100n; C0805
C2, C4: 10u; C0805
C5: 100p; C0805
C6, C7: C-EUC0805; C0805
GSCLK: SJ2W; SJ_2
H5, H6, H7, H8: MOUNT-HOLE3.2; 3,2
IC1: TLC5943; HTSSOP28PWP
IC2: 74HC14D; SO14
IC3: LM1117SOT223-REFLOW; SOT223-R
IC4: MCP9701T-E/TTCTREFLOW; SOT23-R
IR: PINHD-1X3; 1X03
JP1: JP1E; JP1
LED1, LED2, LED3, LED4, LED5, LED6, LED7, LED8, LED9, LED10, LED11, LED12, LED13, LED14, LED15: CLV6A; PLCC6
R1, R2, R3, R4, R5, R6, R7, R8, R9: R-EU_R0805; R0805
SJ3: SJ2W; SJ_2
SOUT: SJ
T1: BSS84; SOT23
U$1: RFBOARD
X1: USBMINIB; USB-MINIB
X2, X3: DCBARRELPTH; DCJACK_2MM_PTH

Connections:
3V3S: C6.2, IC1.26 (XTEST), IC1.28 (VCC), IC2.14 (VCC), T1.3 (D)
+3V3: C3.1, C4.1, IC3.2 (OUT), IC3.4 (OUT1), IC4.1 (VCC), JP1.1, R9.1, T1.2 (S), U$1.2 (VCC1), U$1.7 (NRST), U$1.25 (VCC2)
+12V: LED1.4 (RA), LED1.5 (GA), LED1.6 (BA), LED4.5 (GA), LED4.6 (BA), LED6.4 (RA), LED7.5 (GA), LED7.6 (BA), LED10.5 (GA), LED10.6 (BA), LED11.4 (RA), LED13.5 (GA), LED13.6 (BA), R7.1, SJ3.1, X2.PWR, X3.PWR
BCSEL: IC1.6 (BCSEL), U$1.3 (GPIO4)
BLANK: IC1.2 (BLANK), U$1.20 (XERR)
ERASE: JP1.2, U$1.17 (ERASE)
GND: C1.2, C2.2, C3.2, C4.2, C5.2, C6.1, C7.1, IC1.1 (GND), IC2.1 (I), IC2.7 (GND), IC2.9 (I), IC2.11 (I), IC2.13 (I), IC3.1 (ADJ), IC4.3 (GND), IR.2, R2.2, R5.2, R8.2, U$1.13 (GND2), U$1.14 (GND3), X1.GND, X2.GND, X3.GND
GSCLK_MCU: GSCLK.3, U$1.12 (GSCLK)
IR: IR.1, U$1.6 (GPIO6)
unnamed: LED1.3 (RC), LED2.4 (RA)
unnamed: LED1.2 (GC), LED2.5 (GA)
unnamed: LED1.1 (BC), LED2.6 (BA)
unnamed: LED2.3 (RC), LED3.4 (RA)
unnamed: LED2.2 (GC), LED3.5 (GA)
unnamed: LED2.1 (BC), LED3.6 (BA)
unnamed: LED4.3 (RC), LED5.4 (RA)
unnamed: LED4.2 (GC), LED5.5 (GA)
unnamed: LED4.1 (BC), LED5.6 (BA)
unnamed: GSCLK.2, IC1.25 (GSCLK)
unnamed: LED5.2 (GC), LED6.5 (GA)
unnamed: LED5.1 (BC), LED6.6 (BA)
unnamed: LED7.3 (RC), LED8.4 (RA)
unnamed: LED7.2 (GC), LED8.5 (GA)
unnamed: LED7.1 (BC), LED8.6 (BA)
unnamed: LED8.3 (RC), LED9.4 (RA)
unnamed: LED8.2 (GC), LED9.5 (GA)
unnamed: LED8.1 (BC), LED9.6 (BA)
unnamed: IC1.10 (OUT3), LED3.2 (GC)
unnamed: LED10.2 (GC), LED11.5 (GA)
unnamed: LED10.1 (BC), LED11.6 (BA)
unnamed: LED11.3 (RC), LED12.4 (RA)
unnamed: LED11.2 (GC), LED12.5 (GA)
unnamed: LED11.1 (BC), LED12.6 (BA)
unnamed: LED13.3 (RC), LED14.4 (RA)
unnamed: LED13.2 (GC), LED14.5 (GA)
unnamed: LED13.1 (BC), LED14.6 (BA)
unnamed: LED14.3 (RC), LED15.4 (RA)
unnamed: LED14.2 (GC), LED15.5 (GA)
unnamed: LED14.1 (BC), LED15.6 (BA)
unnamed: LED3.3 (RC), LED4.4 (RA)
unnamed: LED6.3 (RC), LED7.4 (RA)
unnamed: LED9.3 (RC), LED10.4 (RA)
unnamed: LED12.3 (RC), LED13.4 (RA)
unnamed: IC1.11 (OUT4), LED3.1 (BC)
unnamed: IC1.8 (OUT1), LED5.3 (RC)
unnamed: IC1.22 (OUT15), LED6.2 (GC)
unnamed: IC1.21 (OUT14), LED6.1 (BC)
unnamed: IC1.12 (OUT5), LED9.2 (GC)
unnamed: IC1.13 (OUT6), LED9.1 (BC)
unnamed: IC1.14 (OUT7), LED10.3 (RC)
unnamed: IC1.17 (OUT10), LED12.2 (GC)
unnamed: IC1.16 (OUT9), LED12.1 (BC)
unnamed: IC1.18 (OUT11), LED15.3 (RC)
unnamed: IC1.19 (OUT12), LED15.2 (GC)
unnamed: IC1.20 (OUT13), LED15.1 (BC)
unnamed: R4.2, U$1.16 (DDM)
unnamed: GSCLK.1, IC2.6 (O), R6.2
unnamed: IC1.24 (SOUT), SOUT.2
unnamed: R3.2, U$1.15 (DDP)
unnamed: IC1.27 (IREF), R5.1
unnamed: C5.1, IC2.5 (I), R6.1
unnamed: R3.1, X1.D+
unnamed: C1.1, C2.1, IC3.3 (IN), SJ3.2
unnamed: R4.1, X1.D-
unnamed: C7.2, IR.3, R9.2
POWER: T1.1 (G), U$1.8 (GPIO2)
PWR: IC1.EXP (TAB)
RFGND: U$1.1 (GND1), U$1.26 (GND4)
SCLK: IC1.4 (SCLK), U$1.22 (SPCK)
SENSE: R1.2, R2.1, U$1.11 (BLANK)
SIN: IC1.5 (SIN), U$1.23 (SOUT)
SOUT: SOUT.1, U$1.4 (GPIO0)
TEMP: IC4.2 (OUT), U$1.19 (GPIO1)
VBUS: R1.1, SJ3.3, X1.VBUS
VOLTAGE: R7.2, R8.1, U$1.18 (XLAT)
XERR: IC1.23 (XERR), U$1.5 (GPIO5)
XLAT: IC1.3 (XLAT), U$1.21 (GPIO3)

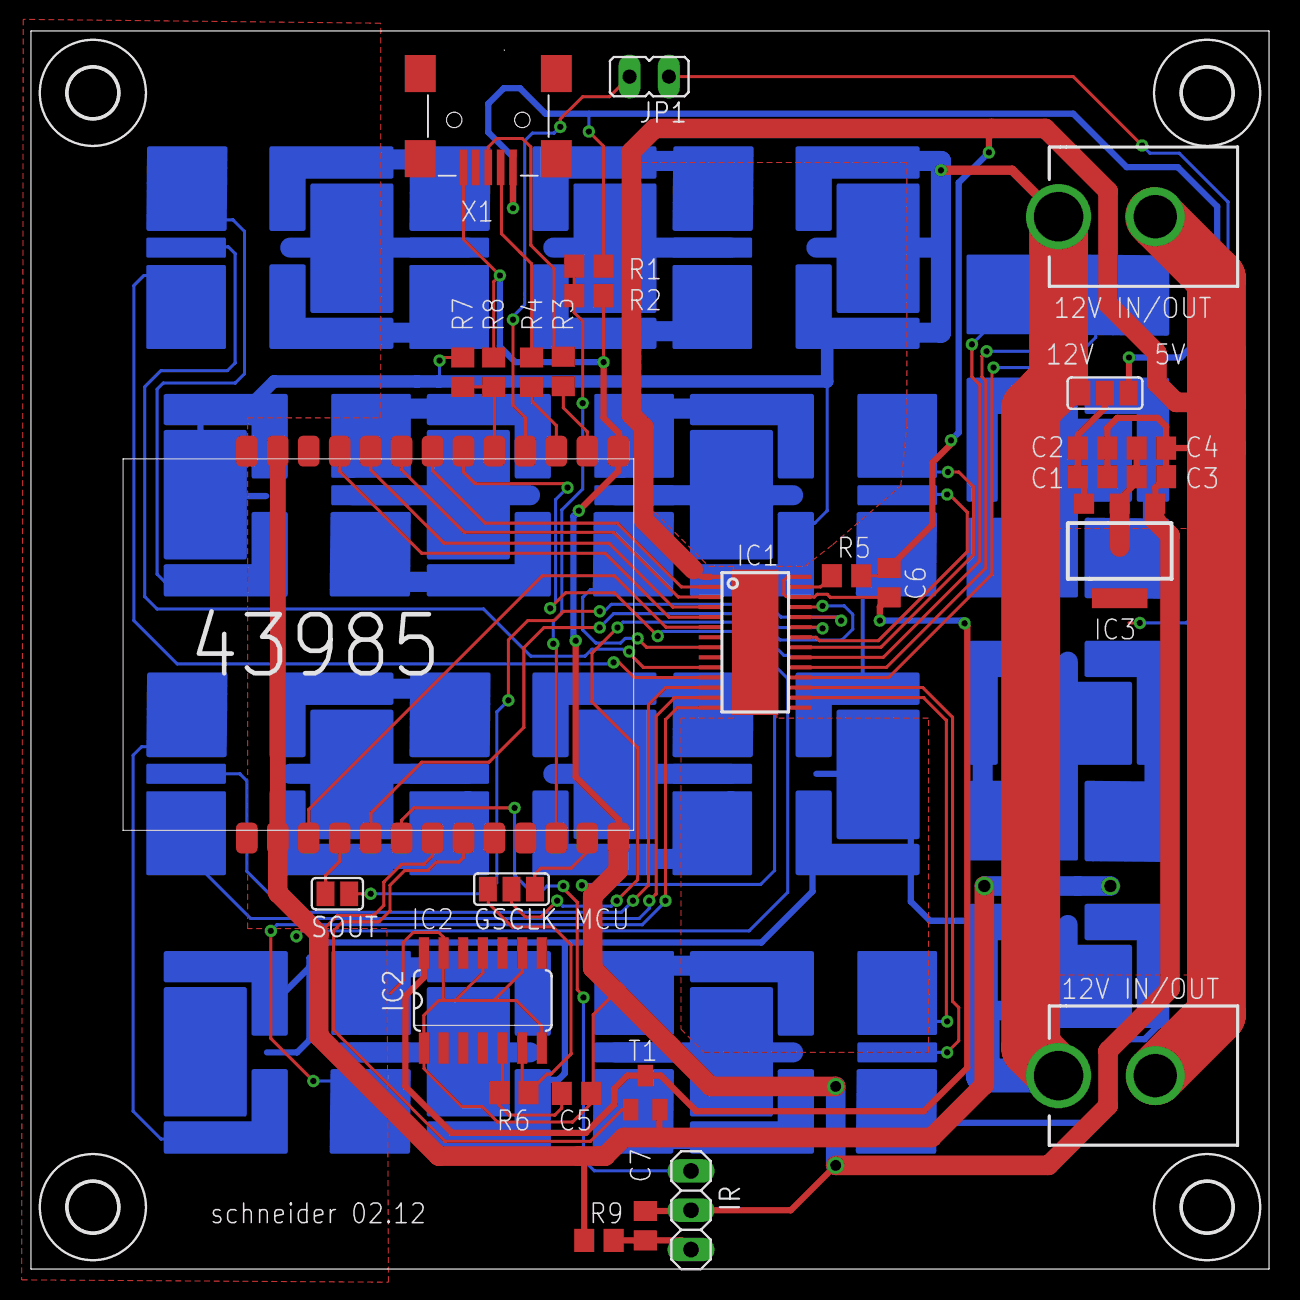
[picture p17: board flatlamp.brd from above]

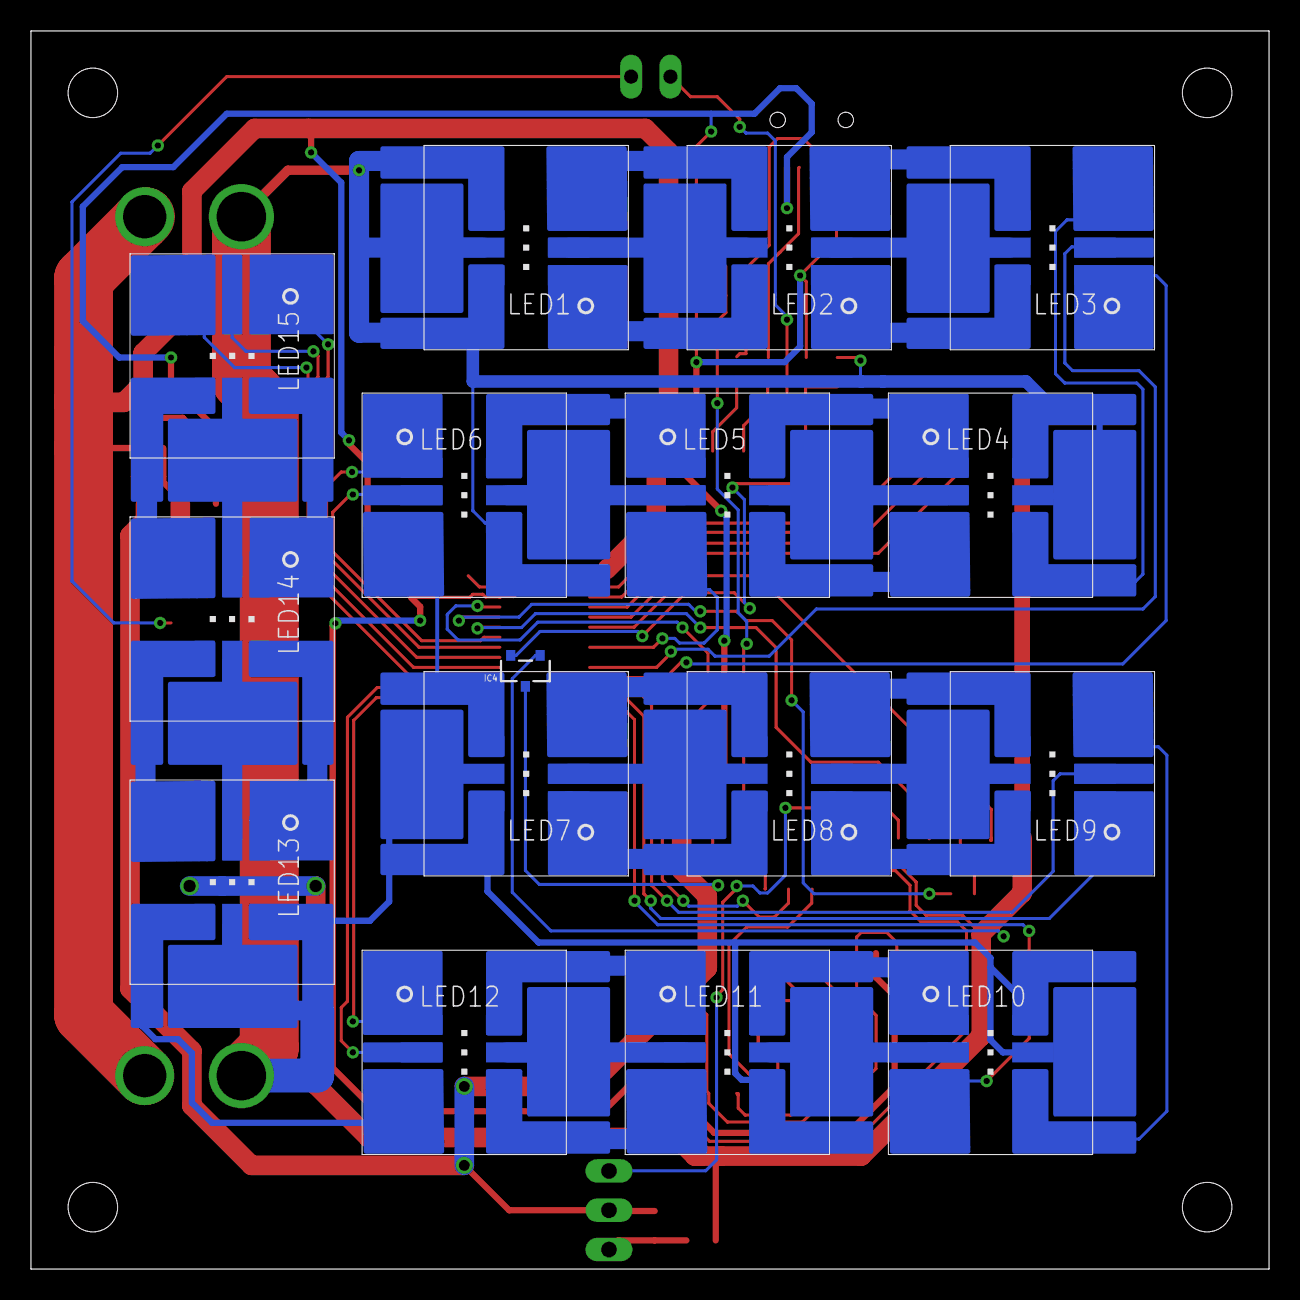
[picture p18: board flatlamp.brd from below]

Board: 2 copper layers, 80.0 x 80.0 mm, 49 parts (16 on the bottom side), 76 nets.

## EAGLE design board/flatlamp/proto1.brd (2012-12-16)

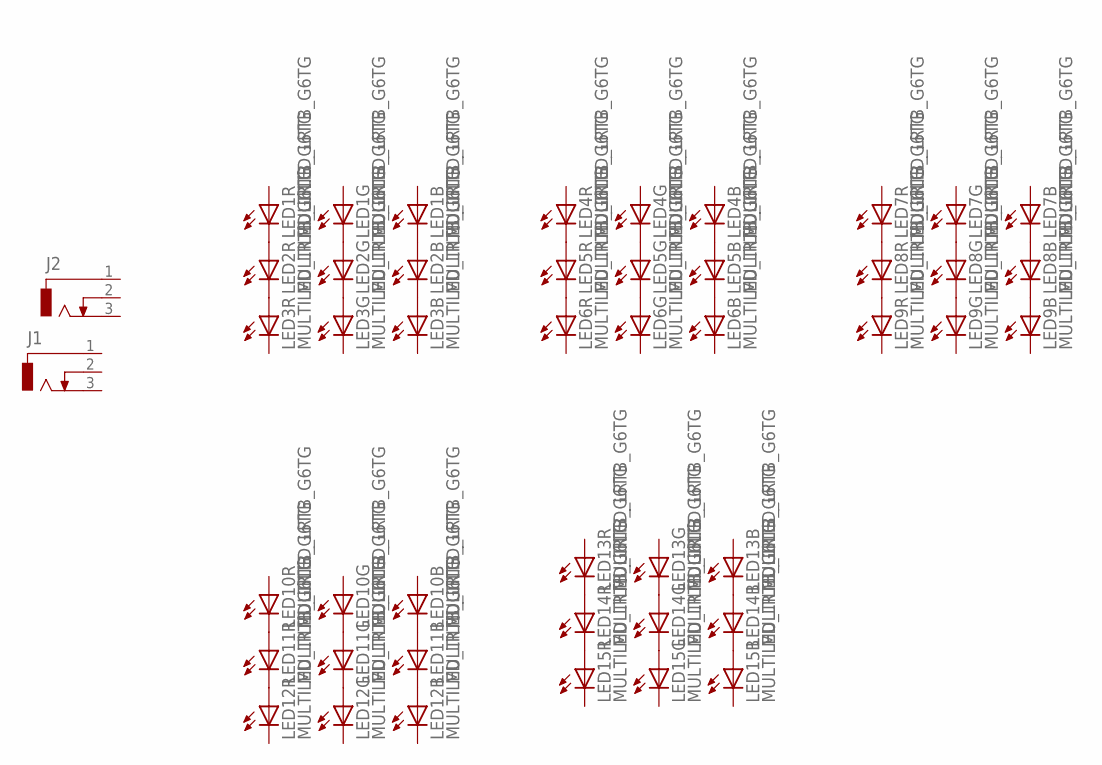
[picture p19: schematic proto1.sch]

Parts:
J1, J2: DCJ0303
LED1, LED2, LED3, LED4, LED5, LED6, LED7, LED8, LED9, LED10, LED11, LED12, LED13, LED14, LED15: MULTILED_LRTB_G6TG; P-LCC-6_TOPLED

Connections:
unnamed: LED1.C1 (C), LED2.A1 (A)
unnamed: LED1.C2 (C), LED2.A2 (A)
unnamed: LED1.C3 (C), LED2.A3 (A)
unnamed: LED2.C3 (C), LED3.A3 (A)
unnamed: LED2.C2 (C), LED3.A2 (A)
unnamed: LED2.C1 (C), LED3.A1 (A)
unnamed: LED4.C1 (C), LED5.A1 (A)
unnamed: LED4.C2 (C), LED5.A2 (A)
unnamed: LED4.C3 (C), LED5.A3 (A)
unnamed: LED5.C3 (C), LED6.A3 (A)
unnamed: LED5.C2 (C), LED6.A2 (A)
unnamed: LED5.C1 (C), LED6.A1 (A)
unnamed: LED7.C1 (C), LED8.A1 (A)
unnamed: LED7.C2 (C), LED8.A2 (A)
unnamed: LED7.C3 (C), LED8.A3 (A)
unnamed: LED8.C1 (C), LED9.A1 (A)
unnamed: LED8.C2 (C), LED9.A2 (A)
unnamed: LED8.C3 (C), LED9.A3 (A)
unnamed: LED11.C1 (C), LED12.A1 (A)
unnamed: LED10.C1 (C), LED11.A1 (A)
unnamed: LED10.C2 (C), LED11.A2 (A)
unnamed: LED11.C2 (C), LED12.A2 (A)
unnamed: LED10.C3 (C), LED11.A3 (A)
unnamed: LED11.C3 (C), LED12.A3 (A)
unnamed: LED13.C1 (C), LED14.A1 (A)
unnamed: LED13.C2 (C), LED14.A2 (A)
unnamed: LED13.C3 (C), LED14.A3 (A)
unnamed: LED14.C1 (C), LED15.A1 (A)
unnamed: LED14.C2 (C), LED15.A2 (A)
unnamed: LED14.C3 (C), LED15.A3 (A)

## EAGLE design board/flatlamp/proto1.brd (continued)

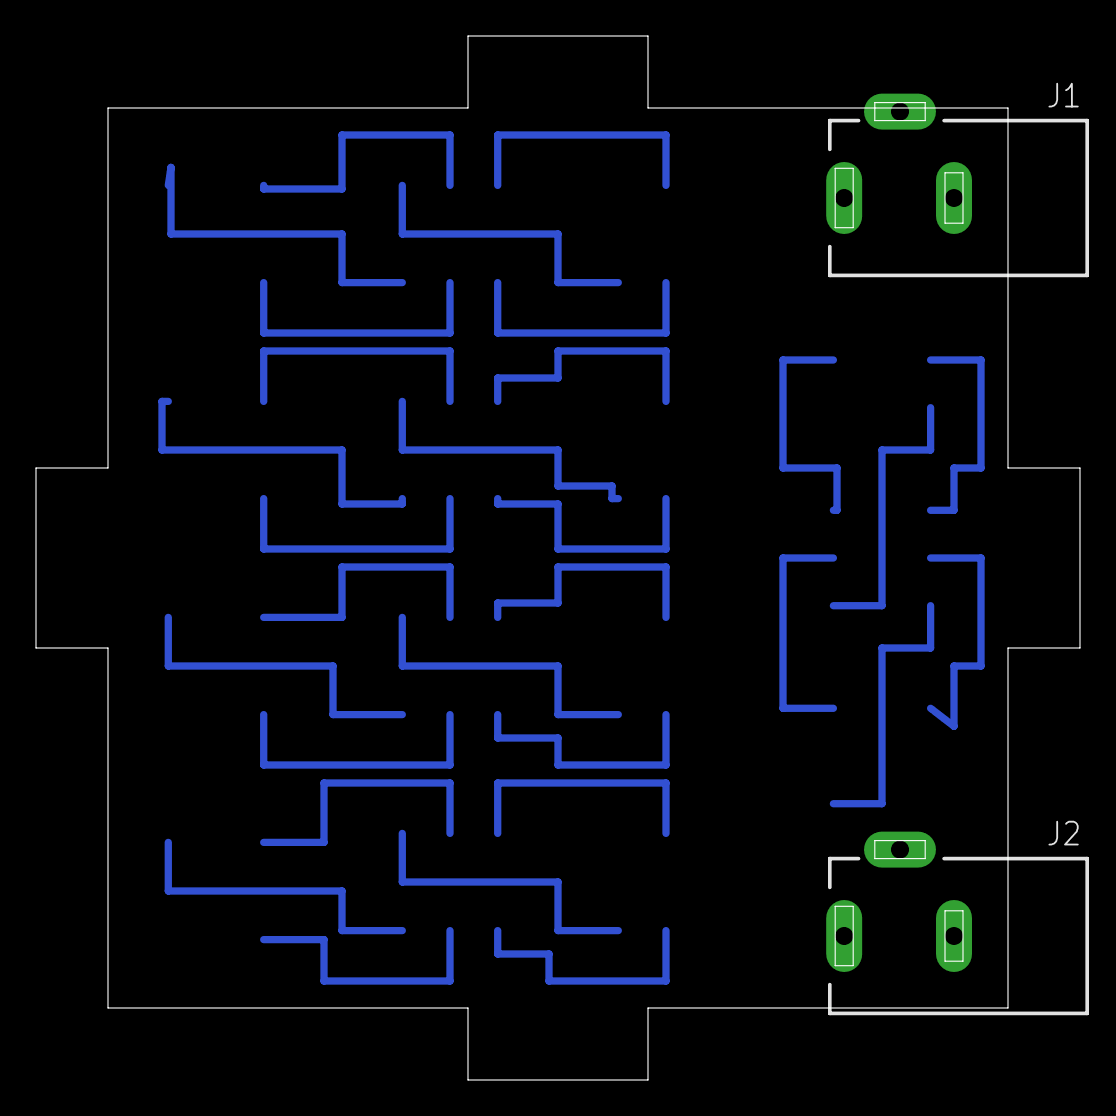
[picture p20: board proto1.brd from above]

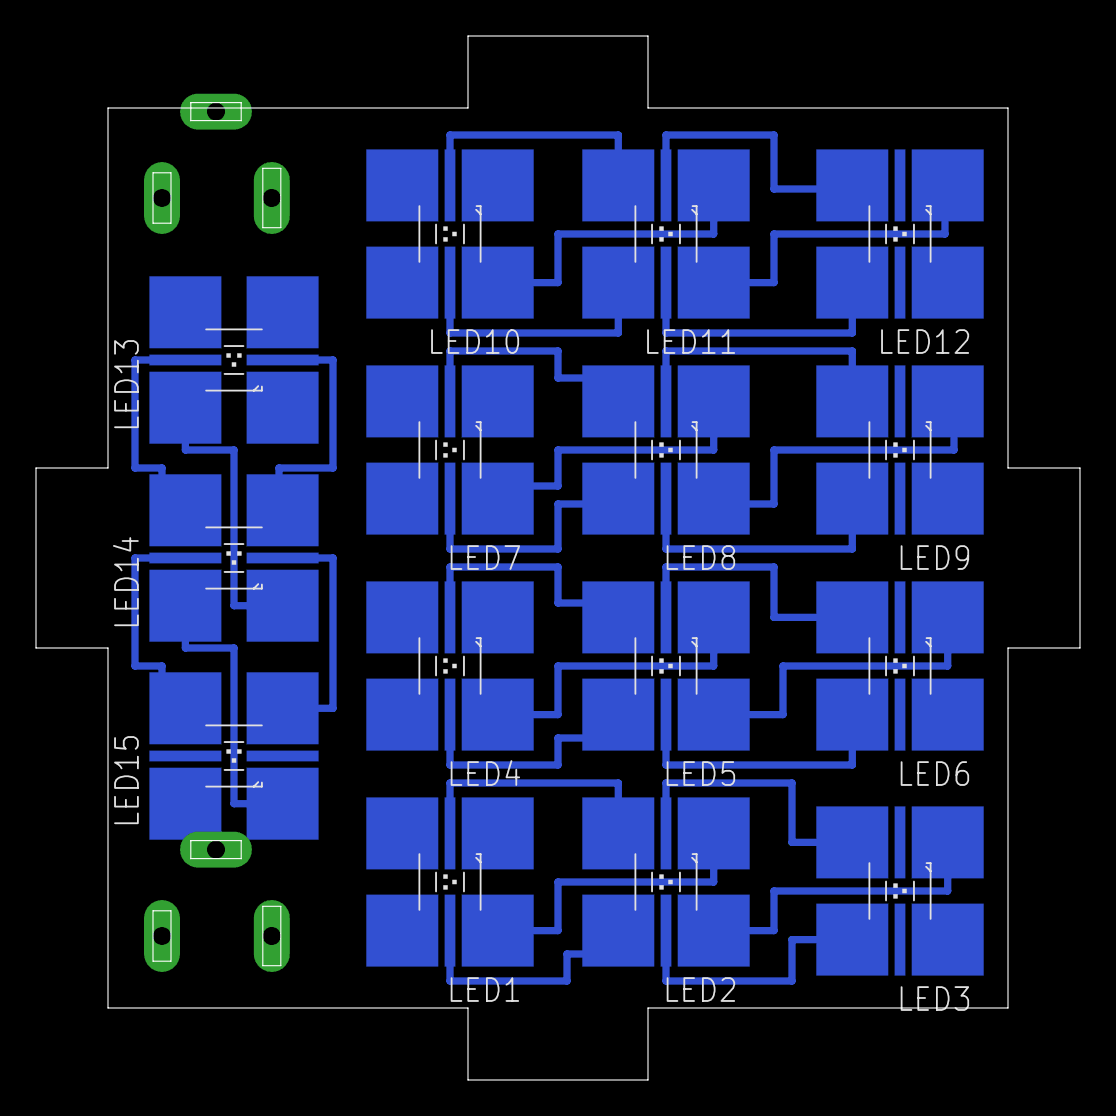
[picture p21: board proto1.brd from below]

Board: 2 copper layers, 58.0 x 58.0 mm, 17 parts (15 on the bottom side), 30 nets.

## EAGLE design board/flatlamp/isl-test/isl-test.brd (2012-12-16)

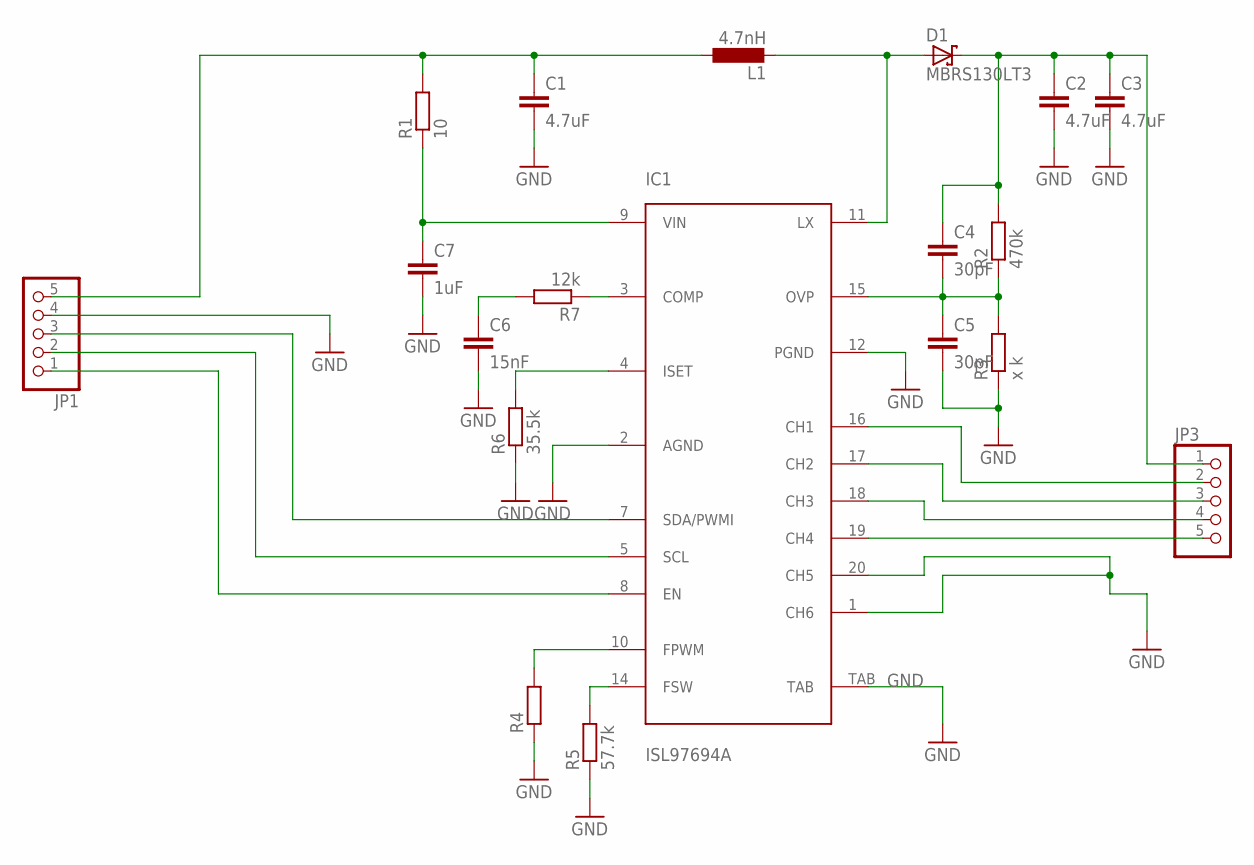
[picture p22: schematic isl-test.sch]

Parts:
C1, C2, C3: 4.7uF; C0805
C4, C5: 30pF; C0603
C6: 15nF; C0603
C7: 1uF; C0603
D1: MBRS130LT3; SMB
IC1: ISL97694A; TQFN-20
JP1, JP3: PINHD-1X5; 1X05
L1: 4.7nH; L1812
R1: 10; R0603
R2: 470k; R0603
R3: x k; R0603
R4: R-EU_R0603; R0603
R5: 57.7k; R0603
R6: 35.5k; R0603
R7: 12k; R0603

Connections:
GND: C1.2, C2.2, C3.2, C5.2, C6.2, C7.2, IC1.1 (CH6), IC1.2 (AGND), IC1.12 (PGND), IC1.20 (CH5), IC1.TAB, JP1.4, R3.1, R4.1, R5.1, R6.1
unnamed: C1.1, JP1.5, L1.1, R1.2
unnamed: D1.A, IC1.11 (LX), L1.2
unnamed: C4.2, C5.1, IC1.15 (OVP), R2.1, R3.2
unnamed: C2.1, C3.1, C4.1, D1.C, JP3.1, R2.2
unnamed: IC1.3 (COMP), R7.1
unnamed: C6.1, R7.2
unnamed: IC1.4 (ISET), R6.2
unnamed: IC1.10 (FPWM), R4.2
unnamed: IC1.14 (FSW), R5.2
unnamed: IC1.8 (EN), JP1.1
unnamed: IC1.5 (SCL), JP1.2
unnamed: IC1.7 (SDA/PWMI), JP1.3
unnamed: IC1.16 (CH1), JP3.2
unnamed: IC1.17 (CH2), JP3.3
unnamed: IC1.18 (CH3), JP3.4
unnamed: IC1.19 (CH4), JP3.5
VIN: C7.1, IC1.9 (VIN), R1.1


Board: 2 copper layers, 27.0 x 26.0 mm, 19 parts (0 on the bottom side), 18 nets.

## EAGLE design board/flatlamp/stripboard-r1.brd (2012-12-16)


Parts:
C1, C3: 100n; C0805
C2, C4: 10u; C0805
C5: C-EUC0805; C0805
H5, H7, H8: MOUNT-HOLE3.2; 3,2
IC1: LM1117SOT223-REFLOW; SOT223-R
IR: PINHD-1X3; 1X03
JP1: JP1E; JP1
LED1, LED2: LEDCHIP-LED0805; CHIP-LED0805
R1, R2, R3, R4, R8, R9, R10, R11, R12: R-EU_R0805; R0805
R5, R6, R7: 100K; M0805
SJ3: SJ2W; SJ_2
T1, T2: IRF7103; SO-8
U$1: RFBOARD
X1: USBMINIB; USB-MINIB
X2, X3: DCBARRELPTH; DCJACK_2MM_PTH
X4: PINHD-1X4/90; 1X04/90

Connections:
+3V3: C3.1, C4.1, IC1.2 (OUT), IC1.4 (OUT1), JP1.1, R12.1, U$1.2 (VCC1), U$1.7 (NRST), U$1.25 (VCC2)
+12V: R10.1, SJ3.1, X2.PWR, X3.PWR, X4.4
ERASE: JP1.2, U$1.17 (ERASE)
GND: C1.2, C2.2, C3.2, C4.2, C5.1, IC1.1 (ADJ), IR.2, LED1.C, LED2.C, R1.2, R5.2, R6.2, R7.2, R11.2, T1.1 (S), T1.3 (S), T2.1 (S), U$1.13 (GND2), U$1.14 (GND3), X1.GND, X2.GND, X3.GND
IR: IR.1, U$1.6 (GPIO6)
LED1: R8.2, U$1.3 (GPIO4)
LED2: R9.2, U$1.5 (GPIO5)
unnamed: T1.8 (D1), X4.1
unnamed: T1.5 (D1), X4.2
unnamed: T2.8 (D1), X4.3
unnamed: LED1.A, R8.1
unnamed: LED2.A, R9.1
unnamed: R3.2, U$1.16 (DDM)
unnamed: R4.2, U$1.15 (DDP)
unnamed: R4.1, X1.D+
unnamed: C1.1, C2.1, IC1.3 (IN), SJ3.2
unnamed: R3.1, X1.D-
unnamed: C5.2, IR.3, R12.2
PWM0: R5.1, T2.2 (G), U$1.12 (GSCLK)
PWM1: R6.1, T1.4 (G), U$1.19 (GPIO1)
PWM2: R7.1, T1.2 (G), U$1.8 (GPIO2)
RFGND: U$1.1 (GND1), U$1.26 (GND4)
SENSE: R1.1, R2.2, U$1.11 (BLANK)
VBUS: R2.1, SJ3.3, X1.VBUS
VOLTAGE: R10.2, R11.1, U$1.18 (XLAT)


Board: 2 copper layers, 50.0 x 50.0 mm, 33 parts (0 on the bottom side), 25 nets.

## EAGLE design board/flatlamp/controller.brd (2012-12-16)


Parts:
B1: BALUN+LP; BALUN0805
C1, C2, C3, C4, C5, C6, C7: C-EUC0402K; C0402K
C8, C9, C10, C11, C12, C13, C14, C15, C16: C-EUC0603K; C0603K
C17: C-EUC0805K; C0805K
JP1, JP2, JP3, JP4, JP5, JP6, JP7, JP8, JP9, JP10, JP11, JP12, JP13, JP14, JP15, JP16, JP17, JP18, JP19, JP20, JP21, JP22, JP23, JP24, JP25, JP35: HEADER-1X1PAD; 1MMPAD
R1, R2: R-EU_R0402; R0402
R3: R-EU_R0805; R0805
TP1, TP2, TP3, TP4: PTR1TP15R; TP15R
TP5: TPTP15SQ; TP15SQ
U1: AT86RF212; 32QN2
U2: MCP24AA32; SOT23-5
U$1: ATSAM3S4AA-AU; LQFP48
Y1, Y2: CRYSTALTHIN; CRYSTAL_3.2X2.5

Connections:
+3V3: C9.1, C13.1, C15.1, C16.1, JP1.1@1, JP1.1@2, JP1.1@3, R1.2, R2.2, U1.15 (DEVDD), U2.4 (VCC), U$1.1 (ADVREF), U$1.7 (VDDIN), U$1.13 (VDDIO), U$1.33 (VDDIO2), U$1.47 (VDDIO3)
ANT: C7.1, TP5.TP
BLANK/PWM1: JP9.1@1, JP9.1@2, JP9.1@3, U$1.35 (PA1/PGMEN1)
CSRF: U1.23 (/SEL), U$1.20 (PA11/PGMM3)
DDM: JP18.1@1, JP18.1@2, JP18.1@3, U$1.43 (DDM/PB10)
DDP: JP17.1@1, JP17.1@2, JP17.1@3, U$1.44 (DDP/PB11)
ERASE: JP14.1@1, JP14.1@2, JP14.1@3, U$1.42 (ERASE/PB12)
GND: B1.2 (GND1), B1.5 (GND2), B1.6 (GND3), C1.2, C2.2, C3.2, C4.2, C8.2, C9.2, C10.2, C11.2, C12.2, C13.2, C14.2, C15.2, C16.2, C17.2, JP2.1@1, JP2.1@2, JP2.1@3, JP16.1@1, JP16.1@2, JP16.1@3, JP20.1@1, JP20.1@2, JP20.1@3, JP21.1@1, JP21.1@2, JP21.1@3, TP4.TP, U1.3 (AVSS1), U1.6 (AVSS2), U1.7 (DVSS1), U1.12 (DVSS2), U1.16 (DVSS3), U1.18 (DVSS4), U1.21 (DVSS5), U1.27 (AVSS3), U1.30 (AVSS4), U1.31 (AVSS5), U1.32 (AVSS6), U1.33 (DIE), U2.2 (GND), U$1.2 (GND), U$1.34 (GND2), U$1.38 (JTAGSEL), Y1.GND1, Y1.GND2, Y2.GND1, Y2.GND2
GPIO0: JP22.1@1, JP22.1@2, JP22.1@3, U$1.23 (PA8/XOUT32/PGMM0)
GPIO1/PWM1: JP7.1@1, JP7.1@2, JP7.1@3, U$1.4 (PB1/AD5)
GPIO2/PWM2: JP10.1@1, JP10.1@2, JP10.1@3, U$1.32 (PA2/PGMEN2)
GPIO3: JP35.1@1, JP35.1@2, JP35.1@3, U$1.6 (PB3/AD7)
GPIO4: JP23.1@1, JP23.1@2, JP23.1@3, U$1.24 (PA7/XIN32/PGMNVALID)
GPIO5/PWM2: JP24.1@1, JP24.1@2, JP24.1@3, U$1.25 (TDI/PB4)
GPIO6: JP25.1@1, JP25.1@2, JP25.1@3, U$1.26 (PA6/PGMNOE)
GSCLK/PWM0: JP5.1@1, JP5.1@2, JP5.1@3, U$1.36 (PA0/PGMEN0)
IRQ: U1.24 (IRQ), U$1.15 (PA15/PGMD3)
MISO: JP13.1@1, JP13.1@2, JP13.1@3, U1.20 (MISO), U$1.19 (PA12/PGMD0)
MOSI: JP12.1@1, JP12.1@2, JP12.1@3, U1.22 (MOSI), U$1.17 (PA13/PGMD1)
unnamed: C5.1, U1.5 (RFN)
unnamed: B1.3 (BALP1), C5.2
unnamed: C6.1, U1.4 (RFP)
unnamed: B1.4 (BALP2), C6.2
unnamed: C1.1, U$1.45 (XOUT/PB8), Y2.2
unnamed: C2.1, U$1.46 (XIN/PB9/PGMCK), Y2.1
unnamed: B1.1 (UNBAL), C7.2
unnamed: C3.1, U1.26 (XTAL1), Y1.2
unnamed: C4.1, U1.25 (XTAL2), Y1.1
unnamed: C12.1, R3.1, U1.28 (EVDD)
unnamed: C8.1, C14.1, C17.1, U$1.8 (VDDOUT), U$1.18 (VDDCORE), U$1.41 (VDDCORE2), U$1.48 (VDDPLL)
unnamed: C11.1, U1.29 (AVDD)
unnamed: JP15.1@1, JP15.1@2, JP15.1@3, R3.2
unnamed: C10.1, U1.13 (DVDD1), U1.14 (DVDD2)
unnamed: TP1.TP, U$1.40 (TCK/SWCLK/PB7)
unnamed: TP2.TP, U$1.39 (TMS/SWDIO/PB6)
unnamed: TP3.TP, U$1.37 (TDO/TRACESWO/PB5)
NRST: JP19.1@1, JP19.1@2, JP19.1@3, U$1.29 (NRST)
RST: U1.8 (/RST), U$1.22 (PA9/PGMM1)
SCL: JP3.1@1, JP3.1@2, JP3.1@3, R2.1, U2.1 (SCL), U$1.28 (PA4/PGMNCMD)
SDA: JP4.1@1, JP4.1@2, JP4.1@3, R1.1, U2.3 (SDA), U$1.31 (PA3)
SLP_TR: U1.11 (SLP_TR), U$1.21 (PA10/PGMM2)
SPCK: JP11.1@1, JP11.1@2, JP11.1@3, U1.19 (SCLK), U$1.16 (PA14/PGMD2)
XERR_READ: JP6.1@1, JP6.1@2, JP6.1@3, U$1.5 (PB2/AD6)
XLAT/PWM0: JP8.1@1, JP8.1@2, JP8.1@3, U$1.3 (PB0/AD4)


Board: 2 copper layers, 26.2 x 33.0 mm, 57 parts (0 on the bottom side), 44 nets.

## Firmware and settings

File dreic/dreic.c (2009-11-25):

#include <stdlib.h>
#include <avr/io.h>
#include <stdint.h>
#include <avr/interrupt.h>
#include <string.h>

#include "lib/uart.h"
#include "serial_handler.h"
#include "zbusneu.h"
#include "packet.h"
#include "cmd_handler.h"
#include "fnordlicht.h"

#define UART_BAUDRATE   230400
#define DREIC_COLOR     'C'
#define DREIC_FADE      'F'

#define DREIC_DONE      "D"

#define PRE_500MS      (6000)
//((F_CPU/512) / 2)
#define PRE_1MS         (PRE_500MS / 500)

volatile uint8_t timebase = 0;
struct packet_t outpacket;
uint8_t sendpacket = 0;
uint8_t debug = 3;
uint8_t raw = 0;

ISR(TIMER0_OVF_vect)
{
    static uint16_t tick = 0;
    TCNT0 = -2;
    tick++;
    if(tick > 2){
        tick = 0;
        timebase = 1;
    }
}

void preparePacket(uint8_t adr, struct packet_t * p)
{
    p->src = 1;
    p->dest = adr;
    p->lasthop = 1;
    p->nexthop = adr;
    p->flags = PACKET_BROADCAST;
    p->iface = 1;
    p->len = 0;
}

void colorPacket(struct packet_t * p, uint8_t adr, uint8_t r, uint8_t g, uint8_t b)
{
    preparePacket(adr, p);
    p->len = 5;
    p->data[0] = CMD_SET_COLOR;
    p->data[1] = r;
    p->data[2] = g;
    p->data[3] = b;
    p->data[4] = 'd';


}
void fadePacket(struct packet_t * p, uint8_t adr, uint8_t r, uint8_t g, uint8_t b, uint16_t speed)
{
    preparePacket(adr, p);
    p->len = 7;
    p->data[0] = CMD_FADE;
    p->data[1] = r;
    p->data[2] = g;
    p->data[3] = b;
    p->data[4] = speed >> 8;
    p->data[5] = speed & 0xff;
    p->data[6] = 'd';

}

void selfassignPacket(struct packet_t * p)
{
    preparePacket(0,p);
    p->len = 1;
    p->data[0] = CMD_STANDALONE;
}

void statePacket(struct packet_t * p)
{
    preparePacket(0,p);
    p->len = 2;
    p->data[0] = CMD_SET_STATE;
    p->data[1] = STATE_REMOTE;
}

uint8_t sendPacket(struct packet_t * p)
{
    if(zbus_ready()){
        memcpy((char*)zbus_txbuf, (char*) p, p->len +PACKET_HEADERLEN);
        zbus_txstart(p->len +PACKET_HEADERLEN);
        return 1;
    }
    return 0;
}

uint8_t fromDigit(uint8_t d)
{
    if(d >= '0' && d <= '9')
        return d-'0';
    return d-'A'+10;
}
uint8_t fromHex(uint8_t * str)
{
    if(debug > 2){
        uart1_puts("From hex:");uart1_putc(str[0]);uart1_putc(str[1]);uart1_putc(str[2]);uart1_puts("\r\n");
    }
    if(str[0] == '#')
        str++;
    return fromDigit(str[0])* 16 + fromDigit(str[1]);
}

void cmd(uint8_t * cmd, uint16_t len)
{
    uint8_t adr,r,g,b;
    uint16_t speed;
    if(debug){
        uart1_puts("cmd=");uart1_putc(cmd[0]);uart1_puts("\r\n");
    }
    switch(cmd[0]){
        case DREIC_COLOR:
            if(debug > 1)
            uart1_puts("Got set color\r\n");
            adr = fromHex(cmd+1);
            r = fromHex(cmd+4);
            g = fromHex(cmd+7);
            b = fromHex(cmd+9);
            colorPacket(&outpacket,adr,r,g,b);
            sendpacket = 1;
        break;
        case DREIC_FADE:
            adr = fromHex(cmd+1);
            r = fromHex(cmd+4);
            g = fromHex(cmd+7);
            b = fromHex(cmd+9);
            speed = (fromHex(cmd+11)<<8) + fromHex(cmd+13);
            fadePacket(&outpacket,adr,r,g,b,speed);
            sendpacket = 1;
        break;
        case 'D':
            debug = cmd[1]-'0';
        break;
        case 'Z':
            zbus_txbuf[0] = 0x42;
            zbus_txbuf[1] = 0x42;
            zbus_txstart(2);
        break;
        case 'W':
            raw = cmd[1]-'0';
        break;
        case 'r':
            raw = 1;
            memcpy((char*)zbus_txbuf, (char*)cmd+1, len-1);
            zbus_txstart(len-1);
        break;
    }
   
}

int main(void)
{
    uint16_t ms500 = PRE_500MS;   //360000;
    uint16_t ms1    = PRE_1MS;      //36
    uint8_t maintenace = 0;
    uint16_t len = 0;
    uint8_t block = 0;
    uint8_t sendmaintenace = 0;
    uint8_t gotcmd = 0;
    uart1_init( UART_BAUD_SELECT(UART_BAUDRATE,F_CPU));
#ifdef USART_USE_0
    uart_init( UART_BAUD_SELECT(UART_BAUDRATE,F_CPU));
#endif

#ifndef USART_USE_0
    zbus_core_init();
    zbus_rxstart();
#else
    PORTC |= (1<<PC4);
#endif

    TCCR0B = 1<<CS02;           //divide by 256
    TIMSK0 |= 1<<TOIE0;         //enable timer interrupt

    sei();
#ifdef USART_USE_0
    uart_puts("123456789");
    while(1){
        uint16_t i = uart1_getc();
        if(!(i & UART_NO_DATA)){    
            uart_putc(i&0xFF);
            if(i == 'b')
                uart1_putc('D');
        }
    }
#endif

    uart1_putc('D');

    if(debug)
    uart1_puts("reset\r\n");
   
    while(1){
        
        if(zbus_ready()){
            zbus_rxstart();
        }
        uint16_t cmdlen = serial_readline();
        if(cmdlen){
            if(debug > 1)
            uart1_puts("readline\r\n");
            gotcmd = 1;
//            ms500 = PRE_500MS;
        }

        if(gotcmd && !sendpacket && !sendmaintenace){
           if(debug > 1)
           uart1_puts("cmd\r\n");
           gotcmd = 0;
           cmd(serial_buffer, cmdlen);
        }

        len = zbus_rxfinish();
        if(len){
            if(debug)
            uart1_puts("Eingang auf zbus\r\n");
            uart1_puts("acR");
            serial_putenc((uint8_t*)zbus_buf,len);
            uart1_puts("ab");

            zbus_rxdone();
            zbus_rxstart();
        }

        if(timebase){
            timebase = 0;
            if(--ms1 == 0){
                ms1 = PRE_1MS;
#ifndef USART_USE_0
//                zbus_core_periodic();
#endif
                if(block)
                    block--;
            }

            if(sendpacket &&  !block){
                if(debug > 1)
                uart1_puts("send\r\n");
                if(sendPacket(&outpacket)){
                    if(debug > 1)
                    uart1_puts("sent\r\n");
                    sendpacket = 0;
                    block = 4;
                    uart1_puts(DREIC_DONE);
                }
            }
            if(sendmaintenace && !block){
                if(sendPacket(&outpacket)){
                    block = 4;
                    sendmaintenace = 0;
                }else if(debug > 2){
                    //uart1_puts("maintenace packet failed\r\n");
                }
            }
            if(--ms500 == 0 && !raw){
                ms500 = PRE_500MS;
                if(debug > 1)
                uart1_puts("mark\r\n");
#ifdef USART_USE_0
                uart_puts("\\0Hello\\1");
#endif
                if(maintenace == 0 && sendpacket == 0){
                    maintenace = 1;
                    selfassignPacket(&outpacket);
#ifndef USART_USE_0
                    sendmaintenace = 1;
#endif
                }else if(maintenace ==1 && sendpacket == 0){
                    maintenace = 0;
                    statePacket(&outpacket);
#ifndef USART_USE_0
                    sendmaintenace = 1;
#endif
                }
            }
        }
    }

    return 0;
}

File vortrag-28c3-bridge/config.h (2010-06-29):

/* vim:fdm=marker ts=4 et ai
 * {{{
 *         fnordlicht firmware next generation
 *
 *    for additional information please
 *    see http://koeln.ccc.de/prozesse/running/fnordlicht
 *
 * (c) by Alexander Neumann <alexander@bumpern.de>
 *     Lars Noschinski <lars@public.noschinski.de>
 *
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
 * For more information on the GPL, please go to:
 * http://www.gnu.org/copyleft/gpl.html
 }}} */

#ifndef _FNORDLICHT_CONFIG_H
#define _FNORDLICHT_CONFIG_H

#define BOARD_0_1       0       //old moodlamp design
#define BOARD_RF_0_1    1       //proto rf board
#define BOARD_RF_0_2    2       //current rf board

#ifndef BOARD
#define BOARD   BOARD_RF_0_2
#endif

#ifndef F_CPU
    #define F_CPU 18432000UL
#endif

#ifndef LED_PORT
#define LED_PORT PORTA
#endif

#ifndef LED_PORT_DDR
#define LED_PORT_DDR DDRA
#endif

#ifndef LED_PORT_INVERT
#define LED_PORT_INVERT 0
#endif

/* color <-> channel assignment */
#define CHANNEL_RED     0
#define CHANNEL_GREEN   1
#define CHANNEL_BLUE    2

#define RC5_DECODER 1
#define RS485_CTRL  1
#define SCRIPT_SPEED_CONTROL 1
#define STATIC_SCRIPTS 1
#define USB_CTRL 1
#define UART_BAUDRATE 115200
#define SERIAL_UART 1

#define CONFIG1_PIN     PB0
#define CONFIG1_PORT     B

#define JUMPER1C1_PIN     PC3
#define JUMPER1C1_PORT    C

#define JUMPER1C2_PIN     PC3
#define JUMPER1C2_PORT    C

#define LED3_PIN     PA4
#define LED3_PORT    A

#define LED2_PIN     PA5
#define LED2_PORT    A

#define LED1_PIN     PA7
#define LED1_PORT    A

#define xRC5C2_PORT     PORTB
#define	xRC5C2_IN       PINB
#define	xRC5C2          PB1			// IR input low active

#define xRC5C1_PORT     PORTD
#define	xRC5C1_IN       PIND
#define	xRC5C1          PD6			// IR input low active

#define ADC_MINBATIDLE  530         //4v

/* debug defines */
#ifndef DEBUG
#define DEBUG 0
#endif

/* include the script intpreter per default */
#ifndef STATIC_SCRIPTS
#define STATIC_SCRIPTS 1
#endif

/* include uart support per default */
#ifndef SERIAL_UART
#define SERIAL_UART 0
#endif

/* disable at keyboard decoder per default (EXPERIMENTAL) */
/* ATTENTION: THIS IS EXPERIMENTAL AND DOES NOT WORK ATM! */
#ifndef AT_KEYBOARD
#define AT_KEYBOARD 0
#endif

/* disable rc5-decoder per default */
#ifndef RC5_DECODER
#define RC5_DECODER 1
#endif

/* disable scripts speed control per default */
#ifndef SCRIPT_SPEED_CONTROL
#define SCRIPT_SPEED_CONTROL 1
#endif

/* fifo size must be a power of 2 and below 128 */
//#define UART_FIFO_SIZE 32
#ifndef UART_BAUDRATE
#define UART_BAUDRATE 19200
#endif

#ifndef PWM_USESCALE
#define PWM_USESCALE
#endif

/* enable this if you want to control a fnordlicht via RS485 */
#if RS485_CTRL

#define TEENSY_SUPPORT

#define RS485_TX_PIN_PORT   C
#define RS485_TX_PIN_PIN    PC4

#define RS485_NRX_PIN_PORT  C
#define RS485_NRX_PIN_PIN   PC5

#define ZBUS_BAUDRATE 115200
/*#define RS485_TX_DDR    DDRD
#define RS485_RX_DDR    DDRD
#define RS485_RX_PORT   PORTD
#define RS485_TX_PORT   PORTD

#define RS485_TX_PIN    PD4
#define RS485_NRX_PIN   PD5*/

#endif

/*#if (RS485_CTRL == 1) && (SERIAL_UART == 1) && !(ROLE == ROLE_MASTER)
#error "RS485_CTRL and SERIAL_UART are mutually exclusive!"
#endif*/


#include <avr/version.h>

/* check for avr-libc version */
#if __AVR_LIBC_VERSION__ < 10604UL
#error newer libc version (>= 1.6.4) needed!
#endif

/* check if cpu speed is defined */
#ifndef F_CPU
#error please define F_CPU!
#endif

/* check if this cpu is supported */
#if !(defined(__AVR_ATmega8__) || defined(__AVR_ATmega88__) || defined(__AVR_ATmega168__) || defined(__AVR_ATmega16__) || defined(__AVR_ATmega324P__)  || defined(__AVR_ATmega644P__) || defined(__AVR_ATmega32__))
#error "this cpu isn't supported yet!"
#endif

/* cpu specific configuration registers */
#if defined(__AVR_ATmega8__)
/* {{{ */
#define _ATMEGA8

#define _TIMSK_TIMER1 TIMSK
#define _UCSRB_UART0 UCSRB
#define _UDRIE_UART0 UDRIE
#define _TXEN_UART0 TXEN
#define _RXEN_UART0 RXEN
#define _RXCIE_UART0 RXCIE
#define _UBRRH_UART0 UBRRH
#define _UBRRL_UART0 UBRRL
#define _UCSRC_UART0 UCSRC
#define _UCSZ0_UART0 UCSZ0
#define _UCSZ1_UART0 UCSZ1
#define _SIG_UART_RECV_UART0 SIG_UART_RECV
#define _SIG_UART_DATA_UART0 SIG_UART_DATA
#define _UDR_UART0 UDR
#define UCSR0A UCSRA
#define UCSR0C UCSRC
#define MPCM0 MPCM
#define UCSZ00 UCSZ0
#define UCSZ01 UCSZ1
#define UCSZ02 UCSZ2
#define UBRR0H UBRRH
#define UBRR0L UBRRL
#define UCSR0B UCSRB
#define RXEN0 RXEN
#define TXEN0 TXEN
#define RXC0 RXC
#define RXB80 RXB8
#define UDR0 UDR

/* }}} */
#elif defined(__AVR_ATmega16__) || defined(__AVR_ATmega32__)
/* {{{ */
#define _ATMEGA16
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

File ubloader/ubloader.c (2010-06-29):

#include <avr/io.h>
#include <avr/wdt.h>
#include <avr/interrupt.h>
#include <avr/eeprom.h>
#include <string.h>

#include "config.h"
#include "leds.h"
#include "flash.h"
#include "ubconfig.h"
#include "ubcrc.h"
#include "ubrs485message.h"
#include "uart.h"
#include "pinutils.h"

#define CHUNKSIZE       32
#define UBBOOTMAGIC     "UBBOOTLOADER"

uint8_t pagedata[SPM_PAGESIZE];
volatile unsigned long timeout;
uint8_t selected = 0;

static void cmd(uint8_t cmd, uint8_t * data, uint16_t len);
static void boot(void);

void (*jump_to_application)(void) = (void *)0x0000;

static void boot(void)
{
    uint8_t tmp = MCUCR;
    MCUCR = tmp | (1<<IVCE);
    MCUCR = tmp & (~(1<<IVSEL));
    jump_to_application();
}

void tx(uint8_t c)
{
    PIN_SET(RS485_TX_PIN);
    PIN_SET(RS485_NRX_PIN);
    UDR0 = c;
    while( !(UCSR0A & (1<<TXC0)) );
    UCSR0A |= (1<<TXC0);
    PIN_CLEAR(RS485_TX_PIN);
    PIN_CLEAR(RS485_NRX_PIN);
}

void sendresult(uint8_t * data, uint8_t len)
{
    uint8_t i;
    tx('\\');
    tx('5');
    for(i=0;i<len;i++){
        tx(data[i]);
    }
    tx('\\');
    tx('2');
    }

int main(void)
{
    uint8_t tmp = MCUCR;
    MCUCR = tmp | (1<<IVCE);
    MCUCR = tmp | (1<<IVSEL);

    leds_init();

    rs485msg_init();
    DDR_CONFIG_OUT(RS485_TX_PIN);
    DDR_CONFIG_OUT(RS485_NRX_PIN);

    PIN_CLEAR(RS485_TX_PIN);
    PIN_CLEAR(RS485_NRX_PIN);
    DDRA = 0xFF;
    PORTA = 0x1;
    UBRR0 = UART_BAUD_SELECT(RS485_BITRATE,F_CPU);
    UCSR0B |= (1<<TXEN0) | (1<<RXEN0);
    wdt_enable(WDTO_2S);
    while(1){
        wdt_reset();
        if( (UCSR0A & (1<<RXC0)) ){
            uint8_t c = UDR0;
            uint8_t type = rs485msg_put(c);
            if( type == UB_BOOTLOADER ){
                uint16_t len = rs485msg_getLen();
                uint8_t *data = rs485msg_getMsg();

                if(len < 3)
                    continue;

                uint16_t crc = ubcrc16_data(data, len-2);
                if( data[len-2] == ((crc>>8) & 0xFF) &&
                    data[len-1] == (crc&0xFF) ){
                    cmd(data[0],data+1,len-3);    
                }else{
                    tx('c');
                    tx(crc>>8);
                    tx(crc&0xFF);
                }
            }
        }
       if( !selected && timeout++ > 1000000UL ){

            PORTA = 0x4;
            boot();
       }
    }
}

static uint8_t compare_flash(uint16_t start, uint8_t len, uint8_t *data)
{
    return 1;
}

static uint8_t compare_eeprom(uint16_t start, uint8_t len, uint8_t *data)
{
    uint8_t buf[100];
    eeprom_read_block(buf,(uint8_t*)start,len);
    if( memcmp(buf,data,len)==0 )
        return 1;
    return 0;
}

static void cmd(uint8_t cmd, uint8_t *data, uint16_t len)
{
    uint8_t ret = 'f';
    uint8_t retlen = 0;
    static uint8_t booted = 0;
    if( cmd == 'B' ){
        data[len]=0;
        if( strcmp((char*)data,UBBOOTMAGIC)==0 ){
            booted = 1;
        }
        return;
    }
    uint16_t start;
    if( cmd == 'S' && booted ){
        selected = 0;
        start = (data[1]<<8)|data[2];
        switch( data[0] ){
            case 'F':
                if( compare_flash(start, len-3, data+3) )
                    selected = 1;
            break;
            case 'E':
                if( compare_eeprom(start, len-3, data+3) )
                    selected = 1;
            break;
        }
        if( selected == 1 ){
            ret = 'S';
            PORTA = 0x2;
        }
    }

    if( !selected )
        return;

    switch(cmd){
        case 'P':
            if( len == CHUNKSIZE+1 ){
                memcpy(pagedata+data[0]*CHUNKSIZE, data+1, CHUNKSIZE);
                ret = cmd;
            }
        break;
        case 'F':
            flash_page(data[0] * SPM_PAGESIZE,pagedata);
            ret = cmd;
        break;
        case 'R':
            start = (data[0]<<8)|data[1];
            len = data[2];
            eeprom_read_block(data,(uint8_t*)start,len);
            retlen = len;
        break;
        case 'E':
            start = (data[0]<<8)|data[1];
            eeprom_write_block(data+2,(uint8_t*)start,len-2);
            ret = cmd;
        break;
        case 'G':
            boot();
        break;
    }

    if( retlen )
        sendresult(data-1,retlen+1);
    else
        sendresult(&ret,1);
}

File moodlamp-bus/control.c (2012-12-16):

#include <stdint.h>
#include <string.h>
#include <avr/interrupt.h>
#include <stdio.h>
#include <stdlib.h>

#include "config.h"
#include "fnordlicht.h"
#include "common.h"
#include "control.h"
#include "pwm.h"
#include "packet.h"
#include "settings.h"
#include <string.h>
#include <avr/wdt.h>
#include "adc.h"
#include "cmd_handler.h"
#include "scripts.h"
#include <avr/sleep.h>

uint16_t timeoutmax = 400;
uint32_t sleeptime=0;
uint32_t sleeptick=0;
uint16_t timeout = 0;
uint8_t  serveradr = 0;
uint16_t control_beacontime = 1000;
uint8_t control_faderunning = 0;
uint16_t time = 0;
uint8_t control_r,control_g,control_b;
uint16_t control_speed, control_time;
uint8_t control_cmd;

#define CONTROL_SEARCHMASTER         1
#define CONTROL_IDENTIFY             2
#define CONTROL_SETUPOK              3
uint8_t control_state = CONTROL_SEARCHMASTER;

void control_init(void)
{
    control_state = CONTROL_SEARCHMASTER;
    control_faderunning = global.flags.running;
}

void control_prepareColor(uint8_t r, uint8_t g, uint8_t b)
{
    control_r = r;
    control_g = g;
    control_b = b;
    control_cmd = CMD_SET_COLOR;
}

void control_prepareFade(uint8_t r, uint8_t g, uint8_t b, uint16_t speed)
{
    control_r = r;
    control_g = g;
    control_b = b;
    control_speed = speed;
    control_cmd = CMD_FADE;
}

void control_prepareFadems(uint8_t r, uint8_t g, uint8_t b, uint16_t time)
{
    control_r = r;
    control_g = g;
    control_b = b;
    control_time = time;
    control_cmd = CMD_FADEMS;
}

void control_prepareFademsalt(uint8_t r, uint8_t g, uint8_t b, uint16_t time)
{
    control_r = r;
    control_g = g;
    control_b = b;
    control_time = time;
    control_cmd = CMD_FADEMSALT;
}

inline void control_update(void)
{
    switch( control_cmd ){
        case CMD_SET_COLOR:
            control_setColor(control_r, control_g, control_b);
        break;
        case CMD_FADE:
            control_fade(control_r, control_g, control_b, control_speed);
        break;
        case CMD_FADEMS:
            control_fadems(control_r, control_g, control_b, control_time);
        break;
        case CMD_FADEMSALT:
            control_fademsalt(control_r, control_g, control_b, control_time);
        break;
    }
    //control_setTimeout();
}

void control_setColor(uint8_t r, uint8_t g, uint8_t b)
{
    cli();
    global_pwm.channels[0].brightness = r;
    global_pwm.channels[0].target_brightness = r;
    global_pwm.channels[1].brightness = g;
    global_pwm.channels[1].target_brightness = g;
    global_pwm.channels[2].brightness = b;
    global_pwm.channels[2].target_brightness = b;
    sei();
}

void control_fade(uint8_t r, uint8_t g, uint8_t b, uint16_t speed)
{
    uint8_t pos;
    global_pwm.channels[0].target_brightness = r;
    global_pwm.channels[1].target_brightness = g;
    global_pwm.channels[2].target_brightness = b;
    for(pos = 0; pos < 3; pos++){
        global_pwm.channels[pos].speed_h = speed >> 8;
        global_pwm.channels[pos].speed_l = speed & 0xFF;
    }
    control_setTimeout();
}

void control_fadems(uint8_t r, uint8_t g, uint8_t b, uint16_t time)
{
    uint8_t pos;
    uint8_t max = 0;
    uint8_t tmp;

    global_pwm.channels[0].target_brightness = r;
    global_pwm.channels[1].target_brightness = g;
    global_pwm.channels[2].target_brightness = b;

    for( pos = 0; pos < 3; pos++){
        tmp = abs(global_pwm.channels[pos].brightness - global_pwm.channels[pos].target_brightness);
        if( tmp > max ){
            max = tmp;
        }
    }
    //speed = steps/tick
    //time = steps / (speed * ticks_per_time)
    //speed = steps * 1000 / ( time * 144 );
    uint32_t lsteps = max * 1024L * 256L; //good enough
    uint16_t speed = lsteps / (time * 144L);
    
    for(pos = 0; pos < 3; pos++){
        global_pwm.channels[pos].speed_h = speed >> 8;
        global_pwm.channels[pos].speed_l = speed & 0xFF;
    }
    control_setTimeout();
}

void control_fademsalt(uint8_t r, uint8_t g, uint8_t b, uint16_t time)
{
    uint8_t pos;
    global_pwm.channels[0].target_brightness = r;
    global_pwm.channels[1].target_brightness = g;
    global_pwm.channels[2].target_brightness = b;

    for(pos = 0; pos < 3; pos++){
        //about 1000 cycles per channel
        //PORTC |= (1<<PC0) | (1<<PC1);
        uint8_t a = global_pwm.channels[pos].brightness;
        uint8_t b = global_pwm.channels[pos].target_brightness;
        if( a == b ){
            PORTC &= ~((1<<PC1) | (1<<PC0));
            continue;
        }
        uint8_t dist = abs(a-b);

        //PORTC &= ~(1<<PC1);
        uint32_t lsteps = dist * 1024L * 256L; //good enough
        uint16_t speed = lsteps / (time * 144L);
        global_pwm.channels[pos].speed_h = speed >> 8;
        global_pwm.channels[pos].speed_l = speed & 0xFF;
        //PORTC &= ~((1<<PC0));
    }

    control_setTimeout();

}
void control_setTimeout(void)
{
    if(timeout)
        timeout = timeoutmax;
    if(global.state != STATE_PAUSE && global.state != STATE_REMOTE){
        global.oldstate = global.state;
        global.state = STATE_PAUSE;
        timeout = timeoutmax;
     }
}

void control_setServer(uint8_t s)
{
    serveradr = s;
    control_state = CONTROL_IDENTIFY;
}

void control_setupOK(void)
{
    control_state = CONTROL_SETUPOK;
}

void control_standby(uint16_t wait)
{
    time = wait;
    global.state = STATE_ENTERSTANDBY;
}

void control_lowbat(void)
{
    if( global.state != STATE_ENTERPOWERDOWN  && global.state != STATE_LOWBAT){
        cmd_setscript(&memory_handler_flash, (uint16_t) &red_blink);
        global.state = STATE_LOWBAT;
    }
}
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

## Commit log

2008-05-18 Fixed timeout for packets Moved update_pwm_timeslots() into the interrupt to prevent flickering during heavy rf usage.
    [fnordlicht.c, pwm.c, rc5_handler.c]
2008-05-20 Added mega32 target Added pwm debug pins
2008-05-31 Added LED_PORT, LED_PORT_INVERT
2008-06-26 Pin changes Optional crc check in rf12.c
2008-06-26 Added mld, funloader and the prototype firmware
2008-09-02 Fixed jump to main program in the bootloader. Bootloader is still not stable on a cold-start
    [funkloader.c]
2008-09-02 Renamed directory for the old breadboard prototype
2008-09-02 Removed uart support to save ram The pwm now only affects the lower three bits of the port. Added dynamic addresses using an uuid supplied by the MLD after the first boot
2008-09-02 SPI is now done in hardware. Added handling for the RF12 reset pin
2008-09-02 Improved raw support Pin configuration for hardware spi
2008-09-03 Fixed typo in pwm.c
    [pwm.c]
2008-09-10 Added pcb data
    [ml-rf.brd, ml-rf.sch]
2008-09-23 Moved uart_file functions to apps
2008-09-23 Uart fix
2008-09-23 New v0.2 board with usb
    [ml-rf-2.brd, ml-rf.brd, ml-rf.sch]
2008-09-23 Improved pin handling in pwm module, still needs some thinking
2008-10-03 Removed internal eagle backup files
    [ml-rf-2.brd]
2008-10-03 Added Version 0.21 of the rf board. Added more clearence to the sides and rearranged silk screen
    [ml-rf.brd, ml-rf.sch]
2008-11-05 New Protocol, and packet switch
2008-11-05 Added bom for materials
    [bom.ods]
2008-11-11 Show all layers of the board
    [ml-rf.brd]
2008-11-21 Added BOM and colored placement chart
    [ml-rf.brd, ml-rf.sch]
2008-11-21 rs485 prototypes
2008-11-23 Added rs485 support with zbus(unstable...)
    [config.h, control.c, fnordlicht.c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]
2008-11-25 Updated bom
    [bom.ods]
2008-11-25 Prototypes for name at E2END
2008-12-21 Added fuses
2008-12-22 Added pwm table tools
2009-02-01 print more human
2009-02-01 Added quote from hope
    [hope-angebot.xls]
2009-02-14 new plugins: ambilight mplayer video filter and sound beatz moodblinker
2009-03-25 Changed symbol to ATMega644P. Removed IRQ solder jumper
    [ml-rf.brd, ml-rf.sch]
2009-03-27 Stromversorgung zeigt nach unten und nichtmehr zum ISP-Stecker. Vierpoliger Busverbinder incl. Stromversorgung. Zusaetzliche Kondensatoren zur Stabilisierung. Drei zusaetzliche Status-LEDs Ein Analog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
    [ml-rf.brd, ml-rf.sch]
2009-03-30 Drei digitale Ausgaenge.
    [ml-rf.brd, ml-rf.sch]
2009-03-30 Moved C1 on top
    [ml-rf.brd]
2009-04-19 V0.3 of board
    [ml-rf.brd, ml-rf.sch]
2009-06-30 Added adc routines
2009-07-01 moved config to global read adc at start and when broadcasting blink red when vcc < 4v
2009-07-01 Switch on the auxiliary leds
2009-07-01 Read hardware revision Read adc value
2009-07-03 Shutdown at 4.0V
2009-07-03 Enter power down after detecting low battery. A lamp with usb, rf and rs485 drwas about 4mA when in power down.
2009-07-05 Inserted all values
    [ml-rf.brd, ml-rf.sch]
2009-07-05 bom for 0.3
2009-07-05 Inserted 0H for the coil Updated bom Added grouped bom
    [ml-rf.brd, ml-rf.sch]
2009-07-05 Added rx and tx led for rf and usb
2009-07-05 Added link to smd soldering
2009-07-05 Added media files for 0.3
    [ml-rf.brd]
2009-07-13 MAX487, AKL166-4, RFM12
    [ml-rf.brd, ml-rf.sch]
2009-09-03 fix power regression
2009-09-03 correct ir pin for 0.21
    [config.h]
2010-01-10 added wdt timer
2010-02-22 Schematic-changes: added license information. Creative Commons: CC-BY-SA 3.0 DE Attribution and Share Alike http://creativecommons.org/licenses/by-sa/3.0/de/
    Changes in trunk 0.3 schematic only:
    removed unused wires where C12 placed in 0.21
    Renewed ml-rf.pdf, sch.png (300dpi)
    in tag 0.2 and 0.21 and trunk (retag 0.3 later)
    [ml-rf.sch]
2010-03-15 updated heat shrink diameter
2010-04-20 aded buslamp
    [buslamp.brd, buslamp.sch]
2010-07-13 Changes in mld scripts: -added colorui.py with telnet interface for mld$ -address lamps with strings not only numbers$ -added debug and usage getopt options$ -added logging$ -replaced print with logg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
2010-12-24 added row test fixed issue with escape sequencing
    [acab.py]
2010-12-24 blink read hex ids error in fadems
    [acab.py]
2012-01-19 buslamp: reworked schematic
    [buslamp.brd, buslamp.sch]
2012-01-19 added bridge layout
    [ub.brd, ub.sch]
2012-12-16 added 16 Bit 288 Hz PWM
2012-12-16 added buffered commands and probabilistic reset command
    [cmd_handler.c, control.c]
2012-12-16 new bom print commands
2012-12-16 new boards
    [controller.GBL, controller.GBO, controller.GBP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]
2014-10-29 feat(board): Second revision of the buslamp board
    [buslamp-r2.brd, buslamp-r2.sch]
2015-05-14 doc(kit-v4): move file into board dir
2015-05-19 ATmega324A with RS485 fix
    [config.h]
2015-12-11 feat(board): Buslamp r4 design
    [buslamp-r4.brd, buslamp-r4.sch]

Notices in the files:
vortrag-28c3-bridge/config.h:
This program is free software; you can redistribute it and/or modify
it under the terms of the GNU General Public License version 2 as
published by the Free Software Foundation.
